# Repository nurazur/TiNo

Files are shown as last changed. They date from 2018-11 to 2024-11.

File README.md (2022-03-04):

# TiNo
[German Version](https://github.com/nurazur/TiNo/blob/master/LIESMICH.md)

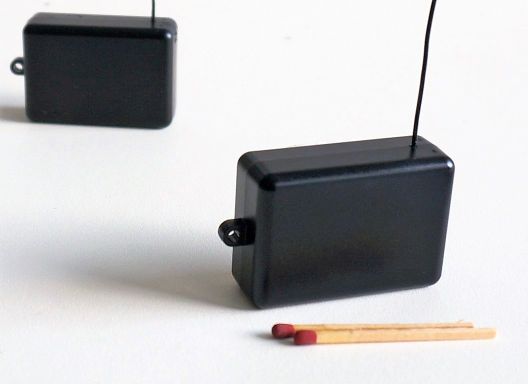
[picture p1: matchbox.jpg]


"**TI**ny **NO**de": battery powered wireless sensor or wireless actor.
Target of the project is the development of small size , cost effective battery powered wireless sensors. The sensors communicate with gateways, like a raspberry pi.
The targets are:

- low cost (BOM under 5 Euro, as of 2020)
- very small size (matchbox)
- ultra low sleep current
- long battery life time: 5 years and more on a CR2032 cell
- long range (what ever this means :-), but its realy long)
- simple to build up
- communication security
- Plug&Play Firmware

Sensors can be almost any, like temperature, relative humidity, air pressure, altitude meter, light intensity, UV Index,
movement detectors, Reed switches, etc. However sensors have to be specified to work down to 2.2V. Otherwise the charge of the battery can not be fully used.

PCBs fit into low cost PVC boxes with the size of a matchbox that are readily available on the market.  

# Features
## General
- Voltage from ca. 1.8V to 3.6V
- Operates with a CR2032 cell up to 5 years
- various PCBs fitting into selected PVC boxes

## Sensors
- HTU21D
- SHT21, SHT20, SHT25
- SHT30, SHT31, SHT35
- BME280 (air pressure sensor)
- DS18B20 (ubiquitous temperature sensor)
- MAX31865 (PT100 temperature Sensor)
- AM312 (PIR movement sensor)
- I2C Bus based sensors can easily be integrated
- 4 digital GPIOs
- up to 4 analog GPIO's (dependent on hardware)

## Radio
- RFM69CW, RFM69HCW, RFM95 Module
- bidirectional communication
- ISM Band (Europe: 433MHz / 868MHz, US:315MHz / 915Mhz)
- 2GFSK Modulation
- Center frequency adjustable
- Frequency correction can be calibrated
- Transmit power from -18 dBm to 20dBm, 10 dBm typ.
- Link budget up to 120dB
- sensitivity -105 dBm typ.
- range t.b.d., but its looong!
- RF communication encrypted
- FEC (Forward Error Correction)
- Interleaver

## Baseband
- Atmel (Microchip) ATMega328p-au
- 32kByte Flash
- sleep current < 2µA mit external crystal 32.768kHz
- sleep current ca. 4µA with internal RC oscillator
- 1 MHz clock allows operating voltage down to 1.8V
- 8 MHz clock for gateway receiver
- I2C bus
- min 4 additional GPIO
- CPU can be locked to avoid reading the flash code

## System / Software
- Open Source Software C++
- Software can easily be adopted individually
- Programming tool is Arduino IDE
- Configuration of Nodes via serial interface (FTDI Adapter)
- configuration data and calibration data reside in EEPROM
- EEPROM encrypted
- Flashing
  - using ISP Adapter or
  - serial with FTDI Adapter and Bootloader
- up to 4 external interrupts (i.e. push buttons) can be configured

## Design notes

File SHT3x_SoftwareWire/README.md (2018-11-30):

# SHT3x
## Arduino library for Sensirion temperature and humidity sensors SHT30, SHT31 & SHT35.
The light version, modiofied by nurazur 2018 for use in mobile Sensors (Code reduction to the bare minimum) and for SoftwareWire
Check for /examples for examples of different use cases.  

The datasheet I followed is:  
https://www.sensirion.com/fileadmin/user_upload/customers/sensirion/Dokumente/2_Humidity_Sensors/Sensirion_Humidity_Sensors_SHT3x_Datasheet_digital.pdf  
For more simple version check the SimpleSHT3x library.  

The constructor structure:  
SHT3x(    int Address = 0x44, //I2C device address, 0x44 or 0x45  
        ValueIfError Value = Zero, //What to return in case of errors. Zero or PrevValue  
        uint8_t HardResetPin = 255, //Number of pin RESET connected to (input from 100 to 255 if not used)  
        SHT3xSensor SensorType = SHT30, //Sensor type, SHT30, SHT31 or SHT35.  
        SHT3xMode Mode=Single_HighRep_ClockStretch //Operation mode , look for "enum SHT3xMode"  
); 

Do not forget about the UpdateData() method: this method polls sensors.

### Supports:  
    Temperature data at Celsius, Kelvin and Fahrenheit scales.  
    Relative humidity data.  
    Absolute humidity data at Torr, mm Hg, Pa, bar, technical and standard atmosphere, psi scales.  
    Data integrity (by CRC8 algorithm) (datasheet/section 4.12).  
    Temperature, relative and absolute humidity tolerances (in dependence from measured values)  
    Calibration (linear) of temperature and humidity data by factors or by reverse sensor values (2 points)  
    Heater On/Off (integrated to SHT3x sensor) (datasheet/section 4.10)  
    Different sensor actions modes (datasheet/section 4.3)  
    Reset: soft (I2C) and hard (by corresponding pin) (datasheet/section 4.9)  
    
### Do not supports:  
    Action in periodic mode (datasheet/section 4.5)  
    Interrupts (datasheet/section 3.5)  

Note 1: by default, the data from sensor updates not faster, than 2 times a second.
For faster update use SetUpdateInterval(uint32_t UpdateIntervalMillisec); but do not exceed the datasheet values (10 measurments per second (100 ms)) because of sensor self-heating (datasheet/section 4.5, at the end of Table 9)  

Note 2: The sensor type affects the tolerance values only.   

Created by Risele for everyone's use (profit and non-profit).  

ALL THESE WOR_DS  
ARE YOURS EXCEPT  
RISELE  
ATTEMPT NO  
namechangING THERE  
USE THEM TOGETHER  
USE THEM IN PEACE

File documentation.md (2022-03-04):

# Projekt Tino
"**TI**ny **No**de" : battery operated wireless sensor or wireless actor.
Object of the project is the development of small size, cost effective battery powered wireless sensors. The sensors communicate with gateways, like a Raspberry Pi. Targets of the development are:

- low cost (BOM below 5 Euro)
- very small size (matchbox)
- very low power consumption
- ultra low sleep current
- long battery life time: 5 years and more on a CR2032 cell
- long range (what ever this means :-), but its really long)
- simplicity
- high grade of communication security
- Plug&Play Firmware
- a certain grade of manufacturability.

Sensors can be almost any, like temperature, relative humidity, air pressure, altitude meter, light intensity, UV Index,
movement detectors, Reed switches, etc. However sensors have to be specified to work down to 2.2V. Otherwise the charge of the battery can not be fully used.

PCBs fit into low cost PVC boxes with the size of a matchbox that are readily available on the market.

## Content
- [Project Description](#project-description)
- [Concept](#concept)
- [How does it work?](#how-does-it-work)
- [IDE setup](#ide-setup)
- [Compile and Flash Software](#compile-and-flash-software)
- [Configuration of Nodes](#configuration-of-nodes)
- [Build a TiNo](#build-a-tino)
- [Electronics](#electronics)
- [Printed Circuit Boards (PCB's)](#printed-circuit-boards-pcbs)
- [Mechanics](#mechanics)

## Project Description
A TiNo sensor takes measurements periodically, for example a temperature reading, and transmits the result over the air to a base station (gateway). The gateway then processes the received data and stores them, which, for example, can be used by cloud services. TiNo can also be used as a monitoring system, for example it can report the opening of doors or windows.

The development started searching for commercially available and affordable enclosures and estimating the required real estate for the PCB's.
The result is a wireless sensor which has been optimized in all important areas in the size of a matchbox. I call it TINO = **TI**ny **NO**de. Later it will become the **TI**ny **N**etw**O**rk. Regarding software there is still a lot of work to do.

## Concept
### Minimal Cost:
<p align='justify'>At the moment the choice of the  ATMega328 processors together with the RFM69CW RF-module is the lowest possible cost variant for makers. There is no need for a LDO or a DC-DC converter. All modules, including the sensor, are directly operated by a 3V CR2032 cell, two AAA batteries or two AA batteries. More cost savings can be realized if the PCB real estate is minimized. This way more PCB's can be accommodated on a multi-frame PCB in production. </p>

### Minimal Size
Due to the used frequencies in the ISM Band we cannot downsize the sensor as desired, without big concessions to performance.
With dimensions of approximately 35 x 50 mm I have had good experiences in the 868MHz ISM Band. The 433MHz ISM Band works sufficient as well.
### Minimal current consumption
Consistent implementation of the possibilities of the ATMega328 processor. Optimization of RF parameters. Optimization of powering the system. Use of energy-saving sensors.
### Maximum Battery life time
The life time of a battery depends on its use case. Mainly Four elements contribute to the battery life time:

1. The battery. TiNo sensors use a CR2032 coin cell. This kind of battery has a typical usable capacity of 200mAh.
2. energy consumption of a single transmit pulse. I optimized the duration of the transmit pulse as well as the power consumption during the pulse.
3. Sleep current. The sleep current was optimized as well. using an external 32.678kHz clock crystal the processor works in sleep mode like a RTC (Real Time Clock). This way I measured sleep currents as low as 1.2µA. Without clock crystal the internal RC oscillator is used. This will consume approximately 4µA, which still is a very good value.
4. The number of transmit pulses per time. With a rate of one pulse per minute the current consumption of the pulses dominates. With a rate of one pulse per hour the sleep current outweighs the current consumption of the transmit pulses.

A typical temperature/humidity sensor transmits one pulse every 30 minutes, so a CR2032 cell should have a life time of 5 years or even longer.
In case you understand German, [in my Blog](https://nurazur.wordpress.com/2018/02/25/batterielebensdauer-eines-tx-nodes-verlaengern-mit-einem-32-768-khz-quarz/) I have explained all this extensively.
### Maximum Range
Optimization of the Layouts. Optimization of the RF parameters. this increases RF sensitivity considerably. Optimization of the RF driver to achieve maximum transmit power.
### Maximum Security
The transmitted message is encrypted. The key cannot be read from flash memory if the processor has been locked for reading before. "Rolling codes" are used so that each message is more or less unique and makes eavesdropping pretty difficult.
### Simplicity
In some areas there is still room for improvement, admitted.
#### Plug&Play Firmware
There is a module available in the Boards Manager of the Arduino IDE.
#### Straightforward Hardware
## How does it work?
<p align='justify'>A TiNo is a sensor which takes periodically measurements and transmits the results using radio frequencies to a gateway. Usually this gateway consists of another TiNo, configured as a receiver node, and a Raspberry Pi. The two communicate over the serial interface. The receiving TiNo receives the RF signal, decodes it, filters out erroneous data and communicates plausible data to the Raspberry Pi. The message is acknowledged if requested. The protocol used between the receiving TiNo and the Raspberry Pi is simple, but it could possibly follow any arbitrary standard, for example RFLink.</p>
<p align='justify'>By default TiNos can react to external events, for example Reed contacts.
A program running on the Raspberry Pi processes and records the data coming from the receiving TiNo. A web application can use these data and display them graphically. However, this is not (yet) part of the TiNo project.
Two TiNo's are required to establish a wireless connection. One needs to be configured as a "sender", the other one as a "receiver".</p>

### Hardware architecture
TiNo Boards are developed as simple as possible:
- directly powered by a 3V battery.
- ATMega328p-au processor
- RFM69CW or RFM69HCW or RFM95 module from HopeRF
- Footprint for a HTU21D/SHT20/SHT21/SHT25 on PCB
- any I2C Sensor can be connected.
- Battery holder (CR2032 cell)
- ISP (in-System-Programming) Adapter, 2x3 Pin row
- FTDI Adapter, 1x6 Pin row
- configurable GPIO's usable for external digital events
- Status LED
- some Boards have a optional SMA socket for an external antenna
- all PCB's are conceptually developed for defined enclosures, but can be used otherwise (of course!)
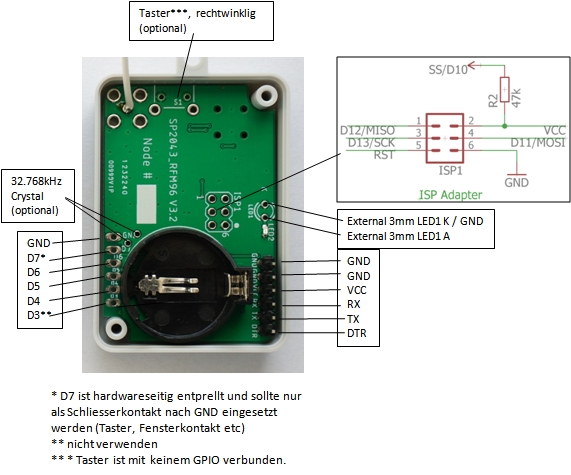
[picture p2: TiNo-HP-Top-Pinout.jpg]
TiNo HP Anschlüsse Oberseite

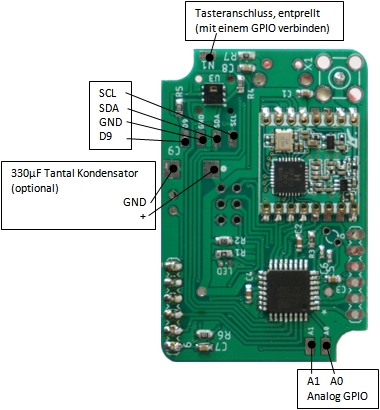
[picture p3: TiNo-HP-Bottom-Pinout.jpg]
TiNo HP Anschlüsse Unterseite

### Software architecture
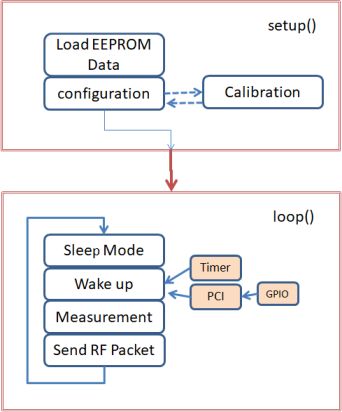
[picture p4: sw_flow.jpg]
TiNo Sensor Software architecture


## IDE setup
### prerequisites
- You should have some solder equipment and solder skills to build up the hardware.
- You should know what the Arduino IDE is.
- You need to install the Arduino IDE on your PC.
- You should know what a "sketch" is.
- The following is easier to understand if you know what a "bootloader" is.
- some basic knowledge of C/C++ is an advantage, but not necessarily required.

In case all that don't tell you anything, then it is better to purchase ready flashed and configured product. Write me an e-mail to nurazur@gmail.com and I will send you the current price list.

### Install TiNo library
- launch Arduino IDE.
- open `File->Preferences`.
- at `Additional Boards Manager URL's` enter this link:
`https://raw.githubusercontent.com/nurazur/TiNo/master/package_tino_index.json`
- Navigate to `Tools->Board`: this opens a long list. at the top, click `Boards Manager...`
- search for `Tiny Node AVR Boards` in the boards manager.
- choose the latest release.
- click `Install`.
This installs all libraries required to operate the wireless protocol.

### Install additional required libraries  
The required sensor libraries are included in the TiNo release package. They can be found in the github repository as well.<br>
Following libraries are required additionally:
- *DallasTemperature*
- *OneWire*

<p align ='justify'>These libraries are currently not part of the TiNo software package. They need to be manually installed by copying into the standard Arduino library directory. The idea behind is that the libraries are of general purpose and could be used for any other arduino project.</p>

## Compile and Flash Software
[Burn Fuses, Flash Bootloader](#burn-fuses-flash-bootloader)<br>
[Define System Password](#define-a-network-system-password)<br>
[Define Sensor Type](#define-the-sensor-type)<br>
[Flash Software](#flash-software)<br>

There are two possibilities to flash code. provided you build a TiNo from scratch, you will need a programmer with [ISP Adapter](https://www.arduino.cc/en/Tutorial/ArduinoISP) in both cases. In case you purchase TiNo's they will be delivered with bootloader already installed.
A programmer can easily be set up using a Arduino UNO. The two possibilities are:
1. Flash a bootloader using the ISP Programmer as a one-time action. Sketches are then flashed using the bootloader and the serial interface, which is in common with the serial interface of the sketch. Advantage: during the development phase you use the same serial connection to flash and test.
2. Flash the sketch directly  without bootloader over the ISP using the programmer. Since there is no bootloader code in flash memory, there is more flash space available.

### Burn Fuses, Flash Bootloader
<p align='justify'>The receiver (or "gateway") needs to be compiled for a board with 8MHz clock. Likewise, a sensor (sender) has to be compiled for a board with 1 MHz clock.
For that, choose the version depending on your personal preferences `Tools->Setup->Gateway, 8MHz, internal Osc` (without bootloader) or `Tools->Setup->Gateway, 8MHz, int.Osc., bootloader` (with bootloader). Analog to the setup of receiver boards, for a sensor board you need to chose, depending on your personal preferences, `Tools->Setup->Sensor, 1MHz, internal Osc.` (no bootloader) or `Tools->Setup->Sensor, 1MHz, int. Osc., bootloader` (with bootloader).</p>

<p align='justify'>Now the "Fuses" have to be programmed ("burned"). These are 3 Bytes of specially protected memory in the processor which determine the general behavior of the processor; The meaning of each bit of these 3 bytes can be studied in the processor's data sheet.
On [this web page](http://www.engbedded.com/fusecalc) it is possible to define or to decode the meaning. Generally speaking we define clock frequency of the processor,  external crystal or internal clock, and the size of the bootloader - if any.</p>
<p align='justify'>The process happens in the Arduino IDE simultaneously with flashing the bootloader. In the life time of a TiNo you do this exactly one time. After that you can flash sketches without "burning fuses". The term "Burn Bootloader" is somewhat confusing, because even if you don't want to use a bootloader you need to select this option just to burn the fuses. It should read exactly as "burn fuses and then flash bootloader". The bootloader itself is a pre-compiled program and is part of the TiNo libraries.</p>

To burn fuses and flash the bootloader (one-time operation):
1. Chose the correct TiNo board `Tools->Board: TiNo Boards` and then `Tools->Setup->...`
2. Connect Arduino Programmer to the ISP connector on TiNo board
3. in the IDE, select the COM Port of the programmer `Tools->Port`
4. In case a Arduino (z.B.UNO) is used as programmer: Click `Tools->Programmer` and then chose "Arduino as ISP" (***not*** "ArduinoISP"!)
5. Click `Tools->Burn Bootloader`. If you choose to burn fuses only, there will be an error message, because the Arduino IDE looks for a bootloader file to be flashed, but there isn't one defined. Don't worry, everything is alright -this is a bug on my side.

#### Alternative: avrdude
<p align='justify'>Power users tend to setup the tool `avrdude` and use it directly from the command line (terminal window). This has a variety of advantages: one can easily query the fuse settings, flash or erase the EEPROM, or flash pre-compiled sketches (.hex files) directly. This also allows to use batch files, so that several steps during the configuration phase can be worked on one by one with one single command. </p>

### Define a Network System Password
The system password is a defined byte sequence in the source code of TiNo _*.ino_ files.
it looks like this (the passphrase is between quotes): `#define KEY  "TheQuickBrownFox"`
The passphrase can consist of letters, numbers or special characters, the only important thing is that it has to have a length of exactly 16 characters. The passphrase `TheQuickBrownFox` is the default.
****It is strongly recommended to change this for your own network.****

### Define the Sensor Type

### Flash Software
#### Flash Software on a board *with* Bootloader:
1. Chose the correct TiNo board `Tools->Board: TiNo Boards` and then `Tools->Setup->...
2. Connect the TiNo board using a FTDA Adapter to your PC. Chose COM Port of serial interface: `Tools->Port`
3. Click `Sketch->Upload`. The sketch will be compiled and then the binary executable is uploaded to the board.

#### Flash  Software on a board *without* Bootloader:
1. Chose the correct TiNo board `Tools->Board: TiNo Boards` and then `Tools->Setup->...`
2. When using a Arduino (i.e. UNO) as programmer: Chose `Tools->Programmer` -> "Arduino as ISP" (***not*** "ArduinoISP"!). Otherwise chose the programmer that you use
3. Connect the programmer with your PC and select its COM Port `Tools->Port`
4. Click `sketch->Upload using Programmer`. Now the sketch will be compiled. Possibly there are warnings, but they can be ignored. Then the binary executable code is uploaded into the flash of the board.

## Configuration of Nodes
After flashing the code TiNo sensor and receiver sketches do not fully work (unfortunately), they need configuration. The EEPROM has to be filled with useful data, the device needs "calibration".

### EEPROMer Python tool
After powering up the TiNo, it reads the EEPROM data. Since the data are encrypted, TiNo decrypts the data and calculates the checksum.

#### If the calculated checksum is identical to the checksum in the EEPROM:
on the serial port TiNo sends the word "CAL?". If 'y' is received within 250ms, then TiNo will enter calibration mode.
Otherwise, if for example no answer is received, then TiNo sends the word "timeout". This is just a debug message. It shows that everything is OK. You see this message only when using a terminal program, such as minicom or TeraTerm.

#### If the calculated checksum is *not* identical to the checksum in the EEPROM:
TiNo enters calibration mode.

The EEPROMer tool or TiNo calibration tool is called *tinocal_v0xx.py*. It runs with python 3 (tested with version 3.7) as well as with Python 2.7. It work under Linux as well as Windows OS.<br>
There are several command line options. The 2 most important are the serial port spec and the Baud rate. The Baud rate for a sender is 4800 Bd, for a receiver it is 38400 Bd. Both the sensor and the receiver can be calibrated with the same tool.

*Important notice:*

> The Tool **tinocal** of version 1 works only on Python 2.7, it throws errors on Python 3.
> The tinocal tools are different for version 1, version 2 and version 3 of TiNo software, they are <em>not</em> compatible with each other. Software of version 1 needs to be calibrated with tinocal version 1, software of version 2 needs to be calibrated with tinocal.009.py of version 2, and software of version 3 needs to be calibrated with tinocal_v010.py of version 3.

<p align ='justify'>When starting the tinocal tool, first the serial port is opened. In case a real FTDA adapter (with DTR line) is connected, this will reset the TiNo. If the DTR line isn't available on your serial adapter, the DTR pin on the TiNo board has to be put to GND manually for a short period. Tinocal then does nothing but listening for the string <em>'CAL?'</em> on the serial interface. As soon as it has received the trigger word, it sends an acknowledgement <em>'y'</em>. The TiNo board on the other side of the interface waits for the acknowledgement and enters calibration mode if it receives <em>'y'</em> within 250ms.</p>

<p align ='justify'>As soon as tinocal signals the calibration mode, the password must be entered. This password is the system password, identical to the <em>KEY</em> parameter in the source code of the sketches. This key also is used to encrypt the messages sent over the air. The EEPROM is encrypted because otherwise a thief could reconfigure a TiNo completely (and do unintentional actions with it) without knowing the encryption key used to transmit messages.</p>

#### Enter Password:
- either: enter the password that is pre-configured in tinocal: `pwd<Enter>` This is just an abbreviation so you don't have to type the password again and again.
- or: there is a command line option that uses the pre-configured password: `-pwd`
- or:  type the password. (it has to be identical with the compiled password in the sketch):<br> `pw,<password><Enter>`

Now tinocal should display "Pass OK", and the actual configuration process can start.
The following commands are supported:

`help` lists all options.

| Command  | Description  | Syntax |
|---|:---|:---|
|`exit` | terminate program
|`help`  or `?` | print this help text
|`c` | measure ADC and store in EEPROM.
|`copy` or `cp` | copy file content to EEPROM. | `cp,<filename>`
|`ri`| read 16 bit integer from EEPROM. | `ri(ead),<addr>`
|`cs`| verify checksum.
|`ft` | write temperature/frequency-correction data table to EEPROM.
|`g` or `get` | store EEPROM content to file. | `g(et),<filename>`
|`ls` or `a`| List EEPROM configuration data.
|`m` | Measure VCC with calibrated values
|`quit` or `q`| terminate program
|`read`  or `r` | read from EEPROM. | `r(ead),<addr>`
|`rf`| read float from EEPROM. | `ri(ead),<addr>`
|`s` | request checksum update and store in EEPROM.
|`t` | send a test RF packet |(ver. 3.x or later)
|`to`| start sending radio OOK signal |(ver. 3.x or later)
|`ts`| put radio into sleep mode |(ver. 3.x or later)
|`tt`| read temperature from RFM69 device |(ver. 3.x or later)
|`vddcal` | calibrate VCC measurement. | `v(ddcal),<VCC at device in mV>`
|`write` or `w`|  write value to to EEPROM.  | `w(rite),<addr>,<value>`
|`wf` | write float value to EEPROM. | `wf,<addr>,<value>`
|`wl` | write long int value to to EEPROM.  | `wl,<addr>,<value>`, value format can be hex
|`wu` | write unsigned int value to EEPROM. | `wu,<addr>,<value>`
|`x` | exit calibration mode and continue with loop()

<p align='justify'>Generally the tinocal tool is interactive, so one can "manually" write meaningful data into the EEPROM. However in practice this is sufficient only for making little changes or for testing the integrity of the EEPPROM data.
More automation is in the works.</p>
The most important activities can be triggered by command line options. Following options are supported:

| Option | Description  | 
|:---|:---|
|-pwd | Send the password as stored in tinocal
|-cs| read checksum from EEPROM
|-ls | List EEPROM data
|-cp,< filename>| copy content of a file to TiNo
|-s | calculate and save checksum to TiNo
|-x | encrypt EEPROM and save Data
|-q | quit tinocal

Here a example of a command line:

`python tinocal_v009.py COM8 38400 -pwd -cp,receive_eeprom.cfg -ls -s -x -q`

In this example tinocal connects to a TiNo board with COM8, 38400 Bd and processes the list of command line options from left to right:
1. `-pwd` sends the password that is provided in the source code of tinocal (can be changed by the user)
2. `-cp,receive_eeprom.cfg` copy the content of the file `receive_eeprom.cfg` from PC to TiNo board.
2. `-ls` list content of the EEPROM.
3. `-s` calculate and save check checksum.
4. `-x` leave calibration mode
5. `-q` quit tinocal

### EEPROM explained:
Following parameters are defined in EEPROM:

| Parameter |  Value | Description |
|:----|:----|:----|
|NODEID| 0-255 | identification of TiNo
|NETWORKID | 0-255 | identification of the network, typically 210 *)
|GATEWAYID | 0-255 | Target identification (Gateway) to which messages are sent
|VCCatCAL | typ. 3300 mV | Value of the supply voltage at the time of calibration
|VCCADC_CAL | typ. 350 | calibrated ADC value.
|SENDDELAY | 0 - 65535 | time in seconds/8 that passes between measurements (max. 145 hours, approx. 6 days). If 0, the RTC timer is deactivated. **)
|FREQBAND | 43, 86 | 43 for the 433MHz Band, 86 for the 868MHz Band
|FREQ_CENTER | i.e. 865.000 | exact center frequency of the sender (must be identical for the entire network)
|TXPOWER | 0-31 | 31 = maximum power, 0 = minimum power, in 1dB Steps (valid for RFM69CW/HCW)
|REQUESTACK | 0 or 1 | defines if a received message must be acknowledged (1) or not (0)
|LEDCOUNT | 0 - 255 | set number of times a received messages is announced by a short blink of the LED ***)
|LEDPIN | 0, 8 | TiNo Pin of the LED (normally Pin D8). A value of zero indicates that the LED isn't used and the pin is free for a interrupt
|RXPIN | 0 | not used. TiNo uses the module *Serial*.
|TXPIN | 1 | not used.
|SDAPIN | 0 - 21 | default: 18 (A4) - SDA pin of the I2C bus
|SCLPIN | 0 - 21 | default: 19 (A5) - SCL pin of the I2C bus
|I2CPOWERPIN | 0- 21 | default: 9 (D9) power supply for sensor components
|PCI0PIN | 0 -21, 128 | usually 3 - 9. Pin used for interrupt PCI0
|PCI0TRIGGER | 0b0000xxxx | kind of interrupt. see below.
|PCI1PIN | 0 -21, 128 | unused interrupts are declared with the value 128
|PCI1TRIGGER |  0b0000xxxx|
|PCI2PIN | 0 -21, 128 |
|PCI2TRIGGER|  0b0000xxxx|
|PCI3PIN| 0 -21, 128 |
|PCI3TRIGGER|  0b0000xxxx|
|USE_CRYSTAL_RTC | 0 or 1 | Version <=2: do not edit!<br>Version 3 and later: editable
|ENCRYPTION_ENABLE | 0 or 1 | 1 = encrypt messages
|FEC_ENABLE | 0 or 1 | 1 = use Forward Error Correction
|INTERLEAVER_ENABLE | 0 or 1 | 1 = use interleaver
|EEPROM_VERSION_NUMBER | auto | **do not edit!** written by the sketch.
|SOFTWAREVERSION_NUMBER| auto | **do not edit!** written by the sketch.
|TXGAUSS_SHAPING | 0,1,2,3 | default: 0. determines BT of Gauss Shaping (advanced)
|SERIAL_ENABLE | 0 or 1 | default 1. determines the activation of the serial port
|IS_RFM69HW | 0 or 1 | 0 = RFM69CW is used. 1 =  RFM69**H**CW is used
|PABOOST | 0, 1, 2, 3| default: 0. Only valid for RFM69HCW: determines the High-Power parameters (advanced)
|FDEV_STEPS | +/- | Frequency correction at room temperature (simple calibration of the 32 MHz crystal of the RFM)
|CHECKSUM | auto | calculated at the end of calibration process and automatically updated (Option 's')

Neue Parameter ab Version 3:

| Parameter |  Value | Description |
|:----|:----|:----|
SENSORCONFIG|0 - 63|bit field configuring sensors supported by hardware
RADIO_T_OFFSET|-128 ... 127| offset in degrees*10 to calibrate the RFM69 temperature sensor
USE_RADIO_T_COMP| 1 or 0 | enable/disable temperature dependent frequency correction
LDRPIN|14,15,16,17| analog GPIO Pin that is connected to a LDR.
PIRPOWERPIN|0-21|GPIO connected to the + (Vdd) terminal of the PIR.  Data terminal needs to be connected to PCI1PIN.
PIRDEADTIME|0-255|period during which the PIR does not respond after it has triggered.
ONEWIREDATAPIN|0-21| Pin where the DS18B20 Data terminal is connected.
PCIxGATEWAYID| 0-255 |target Node when a PCIx interrupt is triggered. x= 0 ... 3

#### Notes:
*) 210 is just to be compatible with the older RFM12B module. On RFM12B modules this value is fixed and cannot be changed.

**) Setting SENDELAY=0 deactivates the timer and activates sleep mode. The microprocessor wakes up only on external interrupts ("PCI").

<p align = 'justify'>***) In standard use cases the LED isn't necessary, it is actually a debug utility. It is possible to determine if the LED blinks when a message is sent. A number > 0 defines the number of messages after start up that are accommodated with a short blink. The default is 1.</p>

#### PCI Trigger Byte Bit Setting:

PCIxTrigger bits 0 and 1:

| Bit Setting | Definition |
|---|---|
|0b0000xx00 | LOW
|0b0000xx01 | CHANGE
|0b0000xx10 | FALLING (default)
|0b0000xx11 | RISING

PCIxTrigger bits 2 and 3:

| Bit Setting | Definition |
|---|---|
|0b000000xx | INPUT
|0b000001xx | OUTPUT
|0b000010xx | INPUT_PULLUP  (default)

Example:
0b00001010 = 0x0A - 10 (Dec) = INPUT_PULLUP und FALLING
This is the default. The internal pullup is part of the hardware debounce circuit with a resistor and a capacitor.

## Building a TiNo
Due to the limited bill of material (BOM) and its simple construction it is really straightforward to build a TiNo, provided some elementary solder skills
### Pre-requisites: What is needed?
#### Hardware
- USB-Serial Adapter: FTDI or compatible, CH340 works as well. Pay attention to the pin-out, und always adjust the jumper or switch to 3.3V! The adapter should have the DTR line available.
- ISP-Programmer (if TiNo is built up from scratch)
- Gateway: something that can open a serial port, read and write to it, display and store messages like a PC, Raspberry Pi, ESP8266,...
- solder iron and accessories. it should be n fine soldering iron for electronics, not an iron that is operated with gas.

#### Software
- Python
- Arduino IDE

### Printed Circuit Board (PCB)
PCB's can be ordered at [seeedstudio](https://www.seeedstudio.com/fusion_pcb.html). From order to delivery it takes 3 weeks, however the quality is good at a reasonable price. Layouts are designed with [Autodesk Eagle](https://www.autodesk.com/products/eagle/overview) and are available at my [github repository](https://github.com/nurazur/TiNo/tree/master/eagle).
### Mechanics (Enclosures)
Two PCB designs are presented:
- The first PCB uses a RFM69HCW / RFM95 pin-out and fits to [Strapubox SP2043 enclosure](http://strapubox.de/modules/uploadmanager11/admin/index.php?action=file_download&file_id=163&location_id=0). In principle this is suited to build a LoRa Node, software is available online.
- The second PCB uses the pin-out of the RFM69CW / RFM12B and fits into [Strapubox MG307 enclosure](https://de.elv.com/search?sSearch=strapubox+MG307). This is the lowest cost variant, the enclosure costs less than 1 EUR, and the RFM69CW can be procured at lower cost than a RFM69HCW.

## Electronics
### Circuit Diagram
The special thing about TiNo is its simplicity. The circuit diagram is really straightforward.

- The core functionality is delivered by its microprocessor and the RF module. The RF module communicates over its SPI bus, these are GPIO's D10(SS) D11(MOSI), D12(MISO) und D13(SCK). Additionally the RF driver needs an external interrupt, GPIO 2 (D2 is used for this). This interrupt triggers when a packet has been received or a packet has been sent.
- These exact GPIO's are being used by the ISP (In-System-Programmer) adapter, because flashing the processor uses the SPI bus as well.
- There is a 10kOhm pullup at the  SS pin (D10) to avoid the RF module to interfere on the SPI bus during the programming process. This pullup causes no additional current in sleep mode.
- Optionally the PCB can be populated with an clock crystal (32.768 kHz). The crystal needs two load capacitors of 6pF or 12pF depending on its specification.
- At start-up and for testing the device a LED is very useful. The LED is connected to digital GPIO 8 (D8). Depending on the TiNo PCB the LED can be used in SMD or wired form factor.
- For practical reasons a FTDI adapter is available. its pin-out is identical to the pin-out of the Arduino Pro Mini. For this reason there are adapters available with this exact pin-out.
- The I2C Bus is connected to GPIO Ports A4 (SCL) und A5(SCK). I2C bus components are supplied through GPIO D9, so in sleep mode they are completely powered off and don't cause sleep currents.  Both lines of the I2C need pull-up resistors. If a HTU21D/SHT2x module is used instead of the on-board IC, then those resistors aren't needed because the pull-ups are already mounted on the module.

### Bill of Material
The prices for components fluctuate strongly. Therefore, the prices shown below are only to be understood as a guide.

| Component | Price | Remark |
|---|---|----|
|ATMega328p-au | ~ 1.20 EUR | 40 pin TQFP
|RFM69CW | ~ 1.50 EUR  |
|HTU21D Sensor | ~ 1.30 EUR | IC's in DFN-6 package cost the same in low qty.
|enclosure | ca. 0.70  - 1.20 | depending on type
|Battery holder | 0.10 |
|other |0.05 | resistors, capacitors, LED in SMD form factor*)

*) a low amount of different values is required, which simplifies the BOM.

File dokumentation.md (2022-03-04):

# Projekt Tino
"**TI**ny **NO**de" : Batteriebetriebener Funksensor oder Funk-Aktor.
Ziel dieses Projekts ist die Entwicklung schnurloser Funk Sensoren,
die über Batterien versorgt werden und z.B. mit dem Raspberry Pi kommunizieren.
Die Entwicklung hat zum Ziel:

- minimale Kosten
- minimale Grösse
- minimaler Stromverbrauch
- maximale Batterielebensdauer
- maximale Reichweite
- maximale Sicherheit
- maximale Einfachheit
- Plug&Play Firmware

Als Sensor kann man so ziemlich alles verwenden, ob Temperatur, Luftfeuchtigkeit, Luftdruck, Höhenmesser, Lichtintensität, UV Index,
Anwesenheitssensoren, Magnetschalter, Erschütterungs-Sensoren, Feuchtigkeitsmesser usw also im Prinzip alle Arten von Sensoren.

Die Leiterplatten passen in im Handel erhältlichen PVC Gehäusen, welche in etwa die Grösse einer Streichholzschachtel haben.
## Inhalt
- [Beschreibung des Projekts](#beschreibung-des-projekts)
- [Das Konzept](#das-konzept)
- [Wie Funktionierts?](#wie-funktionierts)
- [IDE Einrichten](#ide-einrichten)
- [Software Kompilieren und Flashen](#Kompilieren-und-Flashen)
- [Nodes Konfigurieren](#nodes-konfigurieren)
- [Nachbau](#nachbau)
- [Elektronik](#elektronik)
- [Leiterplatten](#leiterplatten)
- [Mechanik](#mechanik) (Gehäuse)

## Beschreibung des Projekts
Der TiNo Sensor macht periodisch eine Messung, z.B. der Umgebungstemperatur und sendet das Ergebnis mit einer kurzen HF Aktivität ("Puls") an eine Basisstation. Diese bereitet das Signal auf und speichert das Ergebnis in einer Datenbank, die z.B. von einem Cloud Service ausgewertet werden kann. Der TiNo kann gleichzeitig auch Ueberwachungsaufgaben übernehmen, wie z.B das Oeffnen einer Türe melden.

Die Idee zu dieser Entwicklung wurde bei mir durch ein Projekt im [deutschen Raspberry Pi Forum](https://forum-raspberrypi.de/forum/thread/7472-batteriebetriebene-funk-sensoren/) ausgelöst.
Ich möchte mich an dieser Stelle nocheinmal herzlich bei allen Beteiligten für die harte Arbeit die dahinter steckt bedanken.
Da wurde mit viel Energie und Enthusiasmus ein System zum Senden und Empfangen von Sensordaten "zusammengebaut", was zur Entwicklung der "TinyTx4" und "TinyRX3" Platinen auf der Basis des ATtiny84a Prozessors geführt hat.

Zunächst ging es mir um technische Verbesserungen: Optimierung des Link-Budgets, ein binäres, wesentlich kürzeres Protokoll, Verbesserungen beim Stromverbrauch und beim Ruhestrom, ich experimentierte HF-seitig unter anderem mit FEC (Forward Error Correction), Interleavern, Baud Raten und Filterbandbreiten, und schliesslich war klar: ein anderer Prozessor muss her, der ATtiny mit seinen 8kB Flash kann nicht mithalten.

Ich begann von vorne. Bei der Gelegenheit habe ich die TiNo Platinen an das Gehäuse und ihren Zweck angepasst und nicht umgekehrt.
Herausgekommen ist ein in allen Parametern optimierter Funksensor in der Grösse einer Streichholzschachtel, welchen ich TINO = **TI**ny **NO**de nenne. Später kann man daraus dann das **TI**ny **N**etw**O**rk machen, denn auf der Softwareseite, speziell am Gateway gibt es noch unendlich viel Arbeit.

## Das Konzept
### Minimale Kosten:
Momentan ist die Auswahl des ATMega328 Processors mit dem RFM69CW HF-Modul die kostengünstigste Variante. Weiterhin kann auf LDO's oder DC-DC Konverter verzichtet werden, da alle Module direkt von einer 3V CR2032 Zelle, zwei AAA Batterien oder zwei AA Batterien betrieben werden können. Weitere Kosten können durch verkleinern der Leiterplatte erzielt werden, so kann man sog. Nutzen (Panels) erzeugen bei denen das selbe Layout 4/6/8 mal auf eine Leiterplatte gebracht wird.
### minimale Grösse
Aufgrund der verwendeten Frequenzen kann man die Baugrösse eines Sensors nicht beliebig verkleinern ohne grosse Zugeständnisse an die Performance zu machen.
Mit Platinenabmessungen von ca. 35 x 50 mm habe ich im 868MHz ISM Band gute Erfahrungen gemacht. Im 433MHz ISM Band funktioniert das ebenfalls durchaus zufriedenstellend.
### minimaler Stromverbrauch
Konsequente Umsetzung der Möglichkeiten des ATMega328 Prozessors. Optimierung der HF Parameter. Optimierung der Stromversorgung. Verwendung stromsparender Sensoren.
### maximale Batterielebensdauer
Die Lebensdauer der Batterie hängt vom Einsatzfall ab. Sie setzt sich im Wesentlichen aus den vier folgenden Komponenten zusammen:
1. die Batterie. Der TiNo hat einen CR2032 Knopfzellenhalter eingebaut. Eine CR2032 hat geschätzt 200mAh nutzbare Kapazität.
2. die Energie die bei einem Sendeimpuls verbraucht wird. In diesem Projekt habe ich die Dauer des Impulses sowie seine Leistung optimiert.
3. der Ruhestrom. Auch der Ruhestrom wurde optimiert. Mit externem Uhrenquarz 32.678MHz arbeitet der Prozessor im Sleep Modus wie eine RTC (Real Time Clock), ich habe Ruheströme von 1.2µA gemessen. Ohne den Uhrenquarz verwendet man den internen RC Oszillator, da messe ich ca. 4µA, das ist aber immer noch ein sehr guter Wert.
4. die Anzahl der Sendepulse pro Zeit. bei einer Rate von einem Puls pro Minute überwiegt der Stromverbrauch der Sendepulse. Bei einer Rate von einem Puls pro Stunde überwiegt der Stromverbrauch durch den Ruhestrom.
Bei einem typischen Temperatur/Luftfeuchte Sensor, der alle 30 Minuten eine Messung sendet kann eine CR2032 Zelle 5 Jahre oder länger halten.
[In meinem Blog](https://nurazur.wordpress.com/2018/02/25/batterielebensdauer-eines-tx-nodes-verlaengern-mit-einem-32-768-khz-quarz/) gibts das Ganze sehr ausführlich erklärt.
### maximale Reichweite
Optimierung des Layouts. Optimierung der HF Parameter. Dadurch verringert sich die Eingangsempfindlichkeit drastisch. Optimierung des HF Treibers um maximale Sendeleistung zu erreichen.
### maximale Sicherheit
Das Sendeprotokoll ist verschlüsselt. Der Schlüssel kann nicht aus dem Flash gelesen werden wenn das Basisband versperrt wurde. Um zu verhindern dass ein einmal aufgezeichnetes Signal bei Wiederholung etwas auslöst wird ein "rolling code" verwendet, der sicherstellt dass jedes Protokoll "einmalig" ist.
### Einfachheit
Da gibts noch Raum für Verbesserung.
#### Plug&Play Firmware
Es wird ein Modul im Boards Manager der Arduino IDE bereitgestellt.
#### Unkomplizierte Hardware
## Wie Funktionierts?
Ein TiNo ist ein Sensor der periodisch eine Messung vornimmt und diese per Funksignal an ein Gateway überträgt.  Dieses Gateway besteht normalerweise aus einem als Empfänger konfigurierten TiNo der an einen Raspberry Pi über dessen seriellen Port angeschlossen ist. Das Gateway empfängt die Funksignale, dekodiert sie und wenn die Daten sinnvoll sind werden diese an den Raspberry Pi weitergegeben. Ausserdem quittiert das Gateway die Nachricht auf Aufforderung. Das zwischen Gateway und Raspberry von mir verwendete Protokoll ist einfach, könnte aber im Prinzip jedem beliebigen Standard folgen, z.B. RFLink.
TiNos können standardmässig auch auf externe Signale reagieren, z.B Tueröffner Kontakte.
Auf dem Raspberry Pi läuft ein Python Programm, welches die vom Gateway ankommenden Pakete aufbereitet und in eine Datenbank schreibt. Eine Web Applikation kann dann auf diese Daten zugreifen und daraus Graphiken etc machen. Dies ist aber (noch) nicht Gegenstand des TiNo Projekts.
Um eine Funkverbindung herzustellen braucht man zwei TiNos, einen als Sensor konfigurierten und einen als Gateway konfigurierten.

### Hardwarearchitektur
Die TiNo Boards sind so einfach wie möglich aufgebaut:
- direkt von einer 3V  Batterie gespeist
- ATMega328p-au Prozessor
- RFM69CW oder RFM69HCW oder RFM95 Modul von HopeRF
- Footprint für einen HTU21D/SHT20/SHT21/SHT25 ist auf der Leiterplatte
- Anschlussmöglichkeiten für einen I2C Sensor beliebiger Wahl.
- Ein Batteriehalter
- ISP (in-System-Programming) Adapter, 2x3 Pin Leiste
- FTDI Adapter, 1x6 Pin Leiste
- je nach Board verschiedene GPIO's die man für alle möglichen digitalen Ereignisse (z.B. Tastendruck) konfigurieren kann
- Status LED
- auf manchen Boards ist eine optionale SMA Buchse vorgesehen (externe Antenne)
- alle Boards sind jeweils für ein bestimmtes Gehäuse konzipiert, können aber auch anderweitig eingesetzt werden.
TiNo HP Anschlüsse Oberseite
TiNo HP Anschlüsse Unterseite
### Softwarearchitektur
TiNo Sensor Software Architektur

## IDE Einrichten
- Arduino IDE starten.
- `File->Preferences` öffnen.
- Unter `Additional Boards Manager URL's` diesen Link eintragen:
`https://raw.githubusercontent.com/nurazur/TiNo/master/package_tino_index.json`
- Navigiere zu `Tools->Board`: eine lange Spalte öffnet sich. Ganz oben auf `Boards Manager...` klicken
- Im Boards Manager nach `Tiny Node AVR Boards` suchen.
- die neueste Freigabe auswählen.
- Auf `Install` klicken.
Dies installiert die Bibliotheken die zum Betrieb des Funkprotokolls gebraucht werden.
### Empfänger (Gateway)
Der Empfänger oder besser "Gateway" wird für ein Board mit 8 MHz Taktfrequenz kompiliert.
hierzu je nach Wahl die Version `Tools->Setup->Gateway, 8MHz, internal Osc` (ohne Bootloader) oder `Setup->Gateway, 8MHz, int.Osc., bootloader` (mit Bootloader)
 auswählen. Dann müssen die "Fuses" dementsprechend programmiert werden.
Dies sind drei Byte geschützter Speicher im Prozessor, die das Verhalten des Prozessors bestimmen; was die einzelnen Bits im Einzelnen bedeuten steht im Datenblatt des Prozessors.
Auf [dieser Webseite](http://www.engbedded.com/fusecalc) kann man die Fuses bestimmen, bzw. dekodieren was sie bedeuten. Im Wesentlichen stellen wir hier ein mit welchem Takt der Prozessor arbeiten soll, ob mit externem Quarz oder internem Taktgeber und ob ein Bootloader verwendet werden soll oder nicht.

In der Arduino IDE wird dieser Vorgang zusammen mit dem Flashen des Bootloaders vorgenommen. Dies macht man für jedes Board genau einmal, danach kann man Sketches flashen ohne die Fuses brennen zu müssen. Der Ausdruck "Burn Bootloader" ist etwas verwirrend, denn wenn wir die Variante ohne Bootloader wählen, müssen wir diesen Vorgang dennoch durchführen um die Fuses zu "brennen".

Fuses flashen (einmaliger Vorgang):
1. Programmer an den ISP des Boards anschliessen
2. COM Port des Programmers auswählen `Tools->Port`
3. Klick auf `Tools->Burn Bootloader`

Alternativ kann man, wenn man ein Poweruser ist, das Tool *avrdude* einrichten und direkt von der Kommandozeile aus verwenden. Dies hat eine Reihe von Vorteilen, da man damit einfach die Fuses abfragen kann, das EEPROM löschen/flashen oder auch fertig kompilierte .hex Dateien direkt auf das Board flashen kann ohne mühsam durch die Arduino IDE klicken zu müssen.
### Sender
Der Sender oder besser "Node" (Knoten in einem Netzwerk) wird für ein Board mit 1 MHz Takt kompiliert. Die "Fuses" müssen dementsprechend programmiert werden. Der Vorgang ist mit dem beim Empfänger identisch.

### Weitere Bibliotheken Installieren
Die notwendigen Bibliotheken für die Sensoren sind im TiNo Package enthalten. Sie stehen auch im Github Repository.
Folgende Bibliotheken braucht man zusätzlich zur Installation des TiNo Boards:
- *DallasTemperature*   (für den DS18B20 Sketch)
- *OneWire*             (für den DS18B20 Sketch)

Diese Bibliotheken sind ab Version 3.0.3 mit im TiNo Package enthalten.

## Kompilieren und Flashen
Dazu braucht man, zumindest kurzfristig, einen Programmer mit [ISP Adapter](https://www.arduino.cc/en/Tutorial/ArduinoISP).
Zum Flashen der Boards gibt es zwei Konzepte. In beiden Fällen braucht man einen Programmer mit [ISP Adapter](https://www.arduino.cc/en/Tutorial/ArduinoISP).
Diesen kann man sich leicht mit einem Arduino UNO oder einem Arduino Nano selbst herstellen. Die Alternativen sind:
1. Einmalig mit dem ISP Programmer auf das Board einen Bootloader flashen. Der eigentliche Sketch wird dann über das serielle Interface des Boards geladen. Vorteil: Während der Entwicklungsphase kann man mit dem selben Interface flashen und testen, ohne das Interface wechseln zu müssen.
2. Den Sketch direkt ohne Bootloader mit einem ISP Adapter flashen. Vorteil: In der Produktionsphase können Nodes in einem einzigen Arbeitsschritt geflasht werden. Da kein Bootloader vorhanden ist, hat man auch mehr Flash Speicher zur Verfügung.

### mit FTDI und USB-Seriell Adapter
Einmaliger Vorgang, wenn man das Board zum ersten mal startet:
- Wenn man einen Arduino (z.B.UNO) als Programmer benutzt: Bei `Tools->Programmer` "Arduino as ISP" auswählen (nicht "ArduinoISP"!)
- Ansonsten den Programmer seiner Wahl auswählen
- COM Port des Programmers einstellen unter `Tools->Port`
- Setup auswählen: "bootloader", je nach Anwendung ist das 'Sensor' oder 'Gateway'.
- `Tools->Burn Bootloader` klicken. Jetzt wird das Board mit den zuvor gewählten Parametern konfiguriert und der Bootloader geflasht.

Normales Flashen:
- COM Port des seriellen Interfaces auswählen: Tools -> Port:
- in der IDE Sketch -> Upload klicken. Jetzt wirdder Sketch kompiliert und geflasht.

### Flashen mit ISP Adapter und Programmer
Einmaliger Vorgang, wenn man das Board zum ersten mal startet:
- Setup je nach Anwendung auswählen, "Sensor" oder "Gateway". Die Option ohne Bootloader wählen.
- den Programmer seiner Wahl auswählen
- COM Port des Programmers einstellen unter `Tools->Port`
- `Tools->Burn Bootloader` klicken.

Normales Flashen:
- Wenn man einen Arduino (z.B.UNO) als Programmer benutzt: Bei `Tools->Programmer` "Arduino as ISP" auswählen (nicht "ArduinoISP"!)
- Ansonsten den Programmer seiner Wahl auswählen
- COM Port einstellen unter `Tools->Port`
- In der Arduino IDE `sketch->Upload using Programmer` klicken. Jetzt kompiliert der Sketch, eventuell mit Warnungen (die man aber ignorieren kann) und lädt den binären Code auf das Board hoch.

## Nodes Konfigurieren
Nach dem Flashen sind die Nodes und die Gateways noch nicht betriebsbereit (leider, wird verbessert). Das EEPROM muss zuerst mit sinnvollen Daten gefüllt, "kalibriert" werden.
### EEPROMer Python tool
nach dem Start eines TiNos liest das TiNo Board das EEPROM. Da die Daten verschlüsselt sind, werden sie zunächst entschlüsselt und die Prüfsumme gebildet.
Wenn die Prüfsumme mit der aus dem EEPROM gelesenen übereinstimmt:
- über den seriellen Port wird der String "CAL?" gesendet. Wenn innerhalb von 250ms ein 'y' zurückkommt, geht der TiNo in den Kalibriermodus.
Kommt keine Antwort, sendet der TiNo, nur als Debugnachricht, ein "timeout". Also nicht wundern über das Timeout, das zeigt an dass alles in Ordnung ist. Man sieht es allerdings nur wenn man das TiNo Board direkt mit einem Terminalprogram (z.B. minicom oder TeraTerm) verbindet.

Wenn die Prüfsumme nicht übereinstimmt:
- Der TiNo geht direkt inden Kalibriermodus.

Da serielle Ports von Computer zu Computer verschieden sind gibt es eine Kommandozeilenoption für den Port. Die Baudrate für den Sender TiNo ist 4800 Baud. Für ein Gateway braucht man moeglichst hohe Baudraten; im Moment ist sie auf 38400 Baud festgelegt. Für beide Konfigurationen kann das selbe Eepromer Tool verwendet werden.

**Wichtige Hinweise:**
Das EEPROMer Tool ist geht mit Python 2.7 oder Python 3.x und wurde auf Linux (Debian) und Windows10 getetstet.
Das EEPROMer Tool tinocal der Version 1 ist in Python 2.7 geschrieben aber läuft unter Python 3 nicht.
Die Python Tools der Versionen 1, Version 2 und Version 3 sind untereinander nicht kompatibel! Firmware der Version 1 muss man mit dem Tool der Version 1 abgleichen, Firmware der Version 2 und später mit dem tool tinocal_v009.py, Firmware der Version 3 mit tinocal_v010.py

Wenn man das EEPROMer Tool startet, öffnet es zunächst den seriellen Port. An einem FTDI Adapter (mit herausgefuehrter DTR Leitung) bewirkt das, dass der angeschlossene TiNo neu startet. Wer keinen Adapter mit DTR Leitung zur Verfügung hat, muss zum Neustart des TiNo die DTR Leitung kurz auf Masse legen und wieder freigeben. Dann wartet das Tool auf das 'CAL?' vom TiNo, und sendet ggf. das 'y' sofort zurück um den Kalibriermodus zu erzwingen.
Sobald das Tool meldet dass man im Kalibriermodus ist, muss man das Passwort eingeben. Dies ist mit dem *KEY* Parameter im Source Code identisch. Derselbe KEY wird auch zum Verschlüsseln des HF Pakets benutzt. Das EEPROM ist verschlüsselt, weil sonst ein Dieb einen TiNo ohne weiteres komplett umkonfigurieren könnte und damit wild in der Gegend herumfunken kann (oder noch Schlimmeres anrichten kann), ohne dass er das Passwort kennen müsste.

Passwort eingeben:
- entweder das im Eepromer Tool hinterlegte Passwort verwenden: `pwd<Enter>` eingeben
- oder ein anderes Passwort verwenden (muss aber immer mit dem kompilierten Passwort identisch sein): `pw,<Passwort><Enter>` eingeben

Nachdem das Tool "Pass OK" meldet, kann man mit dem Konfigurieren beginnen.
Folgende Syntax wird von dem Tool verstanden:
`help` listet die Optionen auf:

| Kommando | Beschreibung  |
|:---|:---|
|`exit` | terminate program
|`help`  or `?` | print this help text
|`c` | measure ADC and store in EEPROM.
|`copy` or `cp` | copy file content to EEPROM. syntax: cp, <filename>
|`cs`| verify checksum.
|`ft` | write temperature / frequency-correction table to EEPROM
|`g` or `get` | store eeprom content to file. Syntax: `g(et),<filename>`
|`ls`| Liste die  EEPROM Konfigurationsdaten.
|`m` | Measure VCC with calibrated values
|`pw`| Passwort. Syntax: `pw,<passwort>`
|`pwd`| Passwort des Auslieferungszustands (default)
|`quit` | beende das Programm
|`read`  or `r` | read from EEPROM. Syntax: `r(ead),<addr>`
|`ri`| read 16 bit integer from EEPROM. Syntax: `ri(ead),<addr>`
|`rf`| read float from EEPROM. Syntax: `ri(ead),<addr>`
|`s` | request checksum update and store in EEPROM.
|`t` | send a test RF packet
|`to`| start sending radio OOK signal
|`ts`| put radio into sleep mode
|`tt`| read temperature from RFM69 device
|`vddcal` | calibrate VCC measurement. Syntax: `v(ddcal),<VCC at device in mV>`
|`write` or `w` |  write value to to EEPROM.  Syntax: `w(rite),<addr>,<value>`
|`wf` | write float value to EEPROM. Syntax: `wf,<addr>,<value>`
|`wl` | write long int value to to EEPROM.  Syntax: `wl,<addr>,<value>`, value format can be hex
|`wu` | write unsigned int value to EEPROM. Syntax: `wu,<addr>,<value>`
|`x` | exit calibration mode and continue with loop()

Das Tool ist ursprünglich interaktiv, d.h. man greift "manuell" auf das EEPROM zu und kann es so konfigurieren. Allerdings ist das nur bis zu einem bestimmten Grad praktisch, z.B. wenn man nur mal schnell eine ID ändern will, oder wenn man nur die Integrität des EEPROMs feststellen will.
Wenn man mehr machen will/muss, wäre eine automatisierte Version praktisch. Ich arbeite daran.

Im Moment kann man die wichtigsten Aktionen durch die Kommandozeile auslösen.
Unterstützt werden zur Zeit folgende Optionen:

| Option | Beschreibung  |
|:---|:---|
-pwd | Sende das im Tool hinterlegte Passwort
-cs|   lies die Prüfsumme vom EEPROM
-ls | Liste der EEPROM Werte
-cp,<Dateiname>| Kopieren des Inhalts einer Konfigurationsdatei zum TiNo
-s | berechnen und speichern der Prüfsumme
-x | EEPROM verschlüsseln und Daten abspeichern
-q | Tool beenden

eine Kommandozeile sieht dann beispielsweise so aus:

`python tinocal_v010.py COM8 38400 -pwd -cp,receive_eeprom.cfg -ls -cs -x -q`

In diesem Fall verbindet sich das Eepromer Tool mit dem TiNo Board auf COM8, 38400 Baud und arbeitet dann die Liste der Optionen in der Reihenfolge ab, also:
1. `-pwd` sendet das im Programm hinterlegte Passwort an da TiNo Board
2. `-cp,receive_eeprom.cfg` kopiert den Inhalt der Datei `receive_eeprom.cfg` vom PC auf das TiNo Board
2. `-ls` listet den Inhalt des EEPROMs.
3. `-cs` liest die Prüfsumme und prüft sie.
4. `-x` verlässt den Kalibriermodus
5. `-q` beendet das Tool

### EEPROM Speicher erklärt:
Diese Parameter sind derzeit im EEPROM gespeichert:

| Parameter |  Wert | Beschreibung |
|:----|:----|:----|
NODEID| 0-255 | die Identitfizierung des TiNo
NETWORKID | 0-255 | Identifizierung des Netzwerks, typisch 210 *)
GATEWAYID | 0-255 | Das Ziel (Gateway) zu dem Nachrichten gesendet werden
VCCatCAL | typ. 3300 mV | Wert der Versorgungsspannung in mV zum Zeitpunkt der Kalibrierung
VCCADC_CAL | typ. 350 | der ADC Wert der bei Anliegen von VCCatCAL kalibriert wurde
SENDDELAY | 0 - 65535 | Zeit in Sekunden/8 die zwischen zwei Messungen vergehen soll (Maximal 145 Stunden, ca 6 Tage). Bei einem Wert von 0 wird der RTC timer deaktiviert. **)
FREQBAND | 43, 86 | 43 für das 433MHz Band, 86 für das 868MHz Band
FREQ_CENTER | z.B. 865.000 | die genaue Mittenfrequenz des Senders (muss für das gesamte Netzwerk identisch sein)
TXPOWER | 0-31 | 31 = maximale Sendeleistung, 0 = minimale Sendeleistung in 1dB Schritten
REQUESTACK | 0 oder 1 | legt fest ob ein empfangenes Telegramm quittiert werden soll (1) oder nicht (0)
LEDCOUNT | 0 - 255 | legt fest ob ein gesendetes Telegramm von einem kurzen Blinken der LED begleitet wird und wie oft ***)
LEDPIN | 0, 8 | Pin an dem die LED hängt (beim TiNo Pin D8). Bei einem Wert von Null wird die LED gar nicht verwendet und ist frei für einen Interrupt verwendbar
RXPIN | 0 | ohne Bedeutung, es wird das Modul *Serial* verwendet.
TXPIN | 1 | ohne Bedeutung.
SDAPIN | 0 - 21 | normalerweise 18 (A4)  Pin der für den SDA des I2C Busses verwendet wird
SCLPIN= | 0 - 21 | normalerweise 19 (A5) Pin der für den SCL des I2C Busses verwendet wird
I2CPOWERPIN | 0- 21 | normalerweise 9 (D9). Pin der für die VCC der I2C Komponenten verwendet wird
PCI0PIN | 0 -21, 128 | normalerweise 3 - 9, Pin der für den Interrupt PCI0 benutzt wird
PCI0TRIGGER | 0b0000xxxx | Triggerart des Interrupts. Wird unten erklärt
PCI1PIN | 0 -21, 128 | ein nicht benutzter externer Interrupt wird mit dem Wert 128 angezeigt
PCI1TRIGGER |  0b0000xxxx|
PCI2PIN | 0 -21, 128 |
PCI2TRIGGER|  0b0000xxxx|
PCI3PIN| 0 -21, 128 |
PCI3TRIGGER|  0b0000xxxx|
USE_CRYSTAL_RTC | 0 oder 1  | Version 2: nicht editieren! wird vom Sketch eingetragen. Ab Version 3:  editierbar
ENCRYPTION_ENABLE | 0 oder 1 | legt fest ob das Telegramm verschlüsselt werden soll
FEC_ENABLE | 0 oder 1 | legt fest ob Forward Error Correction eingesetzt werden soll
INTERLEAVER_ENABLE | 0 oder 1 | legt fest ob ein Interleaver zum Einsatz kommt.
EEPROM_VERSION_NUMBER | auto | **nicht editieren!** wird vom Sketch eingetragen
SOFTWAREVERSION_NUMBER| auto | **nicht editieren!** wird vom Sketch eingetragen
TXGAUSS_SHAPING | 0,1,2,3 | normalerweise 0. Legt fest ob und mit welchem BT Gauss Shaping vorgenommen wird (fortgeschritten)
SERIAL_ENABLE | 0 oder 1 | normal 1. legt fest ob standardmässig der Serielle Port aktiviert sein soll
IS_RFM69HW | 0 oder 1 | 0 : es handelt sich um einen RFM69CW. 1: eshandelt sich um einen RFM69**H**CW
PABOOST | 0, 1, 2, 3| normalerweise 0. nur für RFM69HCW: legt die High-Power Parameter fest (fortgeschritten)
FDEV_STEPS | +/- | Frequenzkorrektur bei Raumtemperatur (einfache Kalibrierung des 32 MHz Quarzes des RFM)
CHECKSUM | auto | wird beim Konfigurieren berechnet und dann eingetragen (Option 's')

Neue Parameter ab Version 3:

| Parameter |  Wert | Beschreibung |
|:----|:----|:----|
SENSORCONFIG|0-63|Bitfeld welches festlegt welche Sensoren von der Hardware unterstützt werden
RADIO_T_OFFSET|-128 ... 127| Offset in Grad*10 um die genauigkeit des RFM Temperatur sensors zu kalibrieren
USE_RADIO_T_COMP| 0 oder 1 | Temperaturabhängige Frequenzkorrektur aktivieren
LDRPIN|14,15,16,17| analoger GPIO Pin wo der LDR angeschlossen ist
PIRPOWERPIN|0-21|GPIO wo der + Anschluss des PIR verbunden ist. Datenpin geht an PCI1PIN
PIRDEADTIME|0-255|Zeit in der der PIR nach dem Auslösen nicht reagiert.
ONEWIREDATAPIN|0-21| Pin wo der DS18B20 Data Pin angeschlossen ist.
PCIxGATEWAYID| 0-255 |Ziel Node wenn ein PCIx Interrupt ausgeloest wurde. x= 0 ... 3

*) 210 ist um mit dem RFM12B Modul kompatibel zu sein. Wert kann bei diesem Modul nicht geändert werden.

**) Wird SENDELAY=0 gesetzt, wird der Timer deaktiviert und  der Sleep Modus des Prozessors aktiviert. Dieser wacht jetzt nur noch bei externen Interrupts ("PCI") auf.

***) Da die LED eigentlich nicht gebraucht wird und nur zum Test einer einwandfreien Funktion dient, kann eingestellt werden ob die LED beim Versenden eines Telegramms aufleuchten soll. Eine Zahl > 0 stellt ein bei wie vielen Telegrammen nach dem Start die LED noch blinken soll. Normalerweise auf 1 gesetzt. Wird LEDCOUNT=255 gesetzt, blinkt die LED immer wenn ein Paket gesendet wird.

PCI Trigger Byte Bitbelegung:

PCIxTrigger bits 0 and 1:

| Bitbelegung | Bedeutung |
|---|---|
0b0000xx00 | LOW
0b0000xx01 | CHANGE
0b0000xx10 | FALLING (Normaleinstellung)
0b0000xx11 | RISING

PCIxTrigger bits 2 and 3:

| Bitbelegung | Bedeutung |
|---|---|
0b000000xx | INPUT
0b000001xx | OUTPUT
0b000010xx | INPUT_PULLUP  (Normaleinstellung)

Beispiel:
0b00001010 = 0x0A - 10 (Dec) = INPUT_PULLUP und FALLING
Dies ist die Normaleinstellung. Der interne Pullup ist Teil der Entprellschaltung mit einem externen Widerstand und einem Kondensator.

---> Bild mit Entprellungsschaltung <----
## Nachbau
Aufgrund der überschaubaren Stückliste und des einfachen Aufbaus ist der Nachbau wirklich kinderleicht, ein wenig Lötfertigkeit vorausgesetzt.
### Vorausetzungen: Was braucht man?
#### Hardware
- USB-Seriell Adapter (FTDI oder kompatibel, CH340 geht auch aber auf das Pinning achten!, und immer den Jumper oder den Schalter auf 3.3V einstellen!)
- ISP-Programmer
- Gateway: etwas das einen seriellen Port öffnen, lesen, schreiben, anzeigen und speichern kann (PC, Raspberry Pi, ESP8266,...)
- Lötkolben und Zubehör. Es sollte ein feiner Lötkolben für Elektronik sein, nicht gerade einer der mit Gas betrieben wird.

#### Software
- Python (am Raspberry Pi bereits vorinstalliert)
- Arduino IDE

### Leiterplatten
Die Leiterplatten bestelle ich gerne bei [seeedstudio](https://www.seeedstudio.com/fusion_pcb.html). Das dauert zwar 3 Wochen von der Bestellung bis zur Lieferung, dafür ist die Qualität aber sehr gut zum vernünftigen Preis. Die Layouts wurden mit [Autodesk Eagle](https://www.autodesk.com/products/eagle/overview) entworfen und sind [hier](https://github.com/nurazur/TiNo/tree/master/eagle) hinterlegt.
### Mechanik (Gehäuse)
ich stelle hier zwei verschiedene Leiterplattendesigns vor:
Die erste Leiterplatte verwendet die RFM69HCW bzw. RFM95 Pinbelegung und ist für das [Strapubox SP2043 Gehäuse](http://strapubox.de/modules/uploadmanager11/admin/index.php?action=file_download&file_id=163&location_id=0) konzipiert. Damit kann man im Prinzip auch einen LoRa Node verwirklichen, entsprechende Software gibt es passend im Netz.
Die zweite Leiterplatte ist mit der Pinbelegung des RFM69CW (kompatibel mit RFM12B) und für das [Strapubox MG307 Gehäuse](https://www.elv.de/strapubox-kunststoff-gehaeuse-mg-307-abs-45-x-30-x-22-mm-grau.html). Dies ist die kostensparendste Variante, da das Gehäuse weniger als 1 EUR kostet und auch der RFM69CW deutlich günstiger zu haben ist als ein RFM69HCW.
## Elektronik
### Schaltplan erklärt
Das Besondere am TiNo ist dass die Schaltung wirklich nicht kompliziert ist.

Das Herzstück ist der Prozessor mit dem HF Modul. Das HF Modul kommuniziert über den SPI Bus, das sind die GPIO's D10(SS) D11(MOSI), D12(MISO) und D13(SCK). Ausserdem benutzt der Treiber einen Interrupt an GPIO D2, der auslöst wenn Daten empfangen werden. Derselbe GPIO D2 wird auch benutzt um das Ende einer Sendesequenz zu signalisieren.
Die selben GPIO's werden vom ISP Adapter benutzt, denn die Programmierung des Prozessors erfolgt ebenso mit SPI Bus. Damit sich das HF Modul beim Programmieren über ISP nicht angesprochen fühlt, braucht es einen 10kOhm Pullup an der SS Leitung (D10). Im Sleep Mode beeinflusst dieser Widerstand den Ruhestrom nicht.

Optional kann der Prozessor im Sleep Modus mit einem externen Uhrenquarz (32.768 KHz) bestückt werden. Der Quarz benötigt noch zwei Lastkondensatoren von je 6pF oder 12pF, je nach Bauart des Quarzes.

Bei der Inbetriebnahme und zum Testen ist eine LED unglaublich hilfreich. Diese wird an GPIO D8 angeschlossen. je nach TiNo Boardausführung kann die LED in SMD und/oder bedrahteter Bauform eingesetzt werden.

Der Bequemlichkeit halber gibt es einen FTDI Adapter. Das Pinout des Adapters ist mit der Pinbelegung eines Arduino Pro Mini identisch, deshalb gibt es auch jede Menge USB-TTL Konverter im Netz mit genau diesem Pinout.

Der I2C Bus wird auf den GPIO Ports A4 (SCL) und A5(SCK) angeschlossen. I2C Bus Komponenten werden durch GPIO D9 versorgt, damit sie im Sleep Modus keinen Strom verbrauchen. Beide Leitungen des I2C Busses brauchen Pullup Widerstände. Wird anstelle des HTU21D/SHT2x Chips ein Modul verwendet, braucht man diese Widerstände nicht da sie auf dem Modul bereits montiert sind.

### Stückliste
Die Preise für Bauteile schwanken stark. Daher sind die angegebenen Preise nur als Anhaltspunkt zu verstehen

| Bauteil | Preis | Bemerkung |
|---|---|----|
ATMega328p-au | ca. 1.20 EUR | März 2022: ca 7.00 EUR
RFM69CW | ca. 1.50 EUR  |
HTU21D Sensor | ca. 1.30 EUR | IC's im DFN-6 Gehäuse kosten fast das selbe (ausser im 50er Pack)
Gehäuse | ca. 0.70  - 1.20 | je nach Typ
Batteriehalter | 0.05 |
Kleinteile |0.05 | Widerstände, Kondensatoren, LED in SMD Bauform *)

*)Ich habe darauf geachtet dass man nicht allzu viele verschiedene Werte benoetigt.

### Messergebnisse

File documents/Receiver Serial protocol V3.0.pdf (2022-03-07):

## TiNo Receiver serial Protocol 3.0

Port Parameters:
Gateway | 38400 Bd 8N1 | 8 Data bits, no parity bit, 1 Stop bit
Sensor | 4800 Bd 8N1 | 8 Data bits, no parity bit, 1 Stop bit

Receiver Message Protocol:
human readable byte sequence, coded with Ascii characters (0-127):

<nodeID><white space><VariableName1>=<value>&<VariableName2>=<value>&...\n

N | LZ | V1 | = | W1 | & | V2 | = | W2 | & | … | & | Vn | = | Wn

\n

N Node ID of Sender
LZ | Separation sign (white space)
Vx | Variable name x
Wx | Value of Variable x – Values must be Integer numbers
& | separation sign (Ampersand)
\n | new line sign (Ascii sign 10)

Available Variables
VariableName Parameter (ger.) | paramter(engl.) | Unit Min | Max | scale factor
d | Entfernung Entfernung | distance distance | cm | -1 | 300 | 10
h | Luftfeuchte | humidity | %rH | 0 | 120 | 100
he | Höhe | height | m | -450 | 100
p | Luftdruck | Air pressure | hPa | 300 | 100
r | Reed-Kontakt | contact | --- | 0 | 1 | 1
t | Temperatur | temperature | degC -40 | 600 | 100
t1 | Temperatur | temperature | degC -40 | 90 | 100
t2 | Temperatur | temperature | degC -40 | 90 | 100
v | Batteriespannung | battery voltage | V | 0 | 5
int | Interrupt | interrupt | --- | 0 | 0xFFFF | 1
rssi | Signalstärke | RSSI | dBm -130 | 0 | 10
lqi | Kanalgüte | link quality indicator --- | 0 | 127 | 1
fo | Frequenzversatz | Frequency offset | Hz | 1
c | Zähler | count | --- | 0 | 1
be | Bitfehler | bit errors | --- | 0 | 127 | 1
sy | Synchronisation | synchronized | --- | 0 | 1 | 1
br | Helligkeit | brightness | --- | 0 | 1

Example

### 23 v=3002&c=243&t=3400&h=5650&int=0&rssi=-835&fo=2014&be=0\n

Message from Node 23: VCC=3.002V, Rolling code =243, Temperature = 34.00 degC, humidity=56.5%rH, no interrupts, RSSI=-83.5dBm, Frequency Offset =2014 Hz, no bit errors

Variables can be listed in any sequence.
All variables a node has available are transmitted.

1023

65535

9999
1100

1000

-30000 30000

Variables Details

VariableName Resolution | Description
d | 1 cm/10 = 1 mm | distance as measured by a ultrasonic sensor
h | 0.01% | relative humidity in percent, can be higher than 100% in rare cases
he | 1m/100=1cm | height over sea level
p | 1hPa/100 | Air pressure
r | digital bit value, 1 or 0
t | degC/100 | Temperature from first sensor
t1 | degC/100 | Temperature from 2nd sensor
t2 | degC/100 | Temperature from 3rd sensor
int | 16 bits, 2 bits per interrupt
int8 | int7 | int6 | int5 | int4 | int3 | int2 | int1
| | | | int x: | | b1 | b0
b1 | b0
0 0 | | no interrupt
0 1 | | CHANGE
1 0 | | FALLING FALLING
1 1
rssi | dBm/10 | signal strength as measured by the Gateway
lqi | | a number indicating if the channel is free of noise or interference.
| | 0 is best, 127 is worst. Not applicable to some radios
fo | 1Hz | Frequency offset measured by the receiver. TiNo Modulation is FM.
| | Tight Frequency tuning control (AFC) is crucial. 0 ist best, values above
| | 5000 are somewhat critical
c
be | 1bit | Bit errors in Packet. Only useful when forward Error correction is used.
| | The amount of bit errors the algorithm detected and corrected.
sy | 1 bit
br | 1bit | Brightness. Measured by a LDR connected to a analog GPIO (A0-A4)
| | 0 corresponds to darkness, 1023 is very light. The resolution depends
| | on the type of LDR (GL5537 is recommended)

Changes in version 3.0 compatred to version 2.2:
Variable fo frequency offset removed. In Version 3.x the measurement of this parameter is not possible. Variable br (brightness) added.

Packet counter, rolling over at some point. Can be a 8-bit value or a 16 bit, value depending on implementation

the gateway is keeping track with the senders rolling code (count value). If track ist lost this signal is set to 0

RISING
In some cases the gateway does not know the exact nature of the interrupt trigger. In this case a CHANGE is signalled.

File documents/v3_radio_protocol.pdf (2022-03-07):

The TiNo Radio Data Protocol | V3.0.2

Preamble, mandatory for all Packets

AA | AA | AA | 2D | XX | LEN | LEN Bytes of Data | Preamble is required by RFM69
0 | 1 | 2 | 3 | 4 | 5 | 6 | 7… | mode of operation
Byte | | Remarks
0,1,2 | Preamble for frequency Sync
3 | Syncword 1. fixed to 2D for compatibility with RFM12B
4 | Syncword 2. Network ID, defined by user, set to D2 for compatibility with RFM12B
5 | LEN = length of Data block
6…6+LEN Data Block

Data Block (TiNo Sensor Protocol)

D | S | F | V | C | T | H | P | B | LEN = 8 (optional 12)
Param. | #Bits | Remarks
D | 8 | Destination, the Target ID
S | 8 | Sender Node ID
F | 8 | Flags:
x | 0 | 0 | x | x | x | x | x | x= 1 or 0 depending on function
7 | 6 | 5 | 4 | 3 | 2 | 1 | 0

0 Heartbeat (system is healthy)
| 1 PCI 0
2 PCI 1 | Pin Change Events, mapped to Ports in
3 PCI 2 | EEPROM of Sender. 1 = a event happened, 0 = no event happened
| 4 PCI3
5 0 = TiNo Sensor Protocol, 1= Alternate Protocol
6 ACK Must be set to 0.
7 Request ACK from receiver, when set to 1
V | 12 | unsigned int | Voltage measurement. resolution 1 mV, offset 0 mV
possible values range from 0 to 4096 (0 to 4.096V)
C | 8 | unsigned char | counter, incremented for each packet sent, runs over from 255 to 0
T | 12 | unsigned int | Temperature Measurement
Resolution 0.04 degC, offset +40 degC
encode: | T = ( t[degC] + 40 ) *25
decode: | t[degC] = T/25.0 - 40
H | 8 | unsigned char | Humidity Measurement
Resolution 0.5 %RH, offset 0%RH
encode: | H = h[%RH] * 2
decode: | h[%RH] = H/2.0
P | 22 | unsigned int | Air Pressure Measurement
Resolution: 0.01 hPa, offset 0 hPa
encode: | P = p[hPa] * 100
decode: | p[hPa] = P/100.0
B | 10 | unsigned int | analog Value, for example Brightness Measurement

Data Block - Alternate Protocol (General Description)

D | S | F | C | Any other data
0 | 1 | 2 | 3 | 4…LEN | LEN = user defined , must be modulo 4 if encryption is used
LEN=4 indicates empty data block
Param. | #Bits | Remarks
D | 8 | Destination, the Target ID
S | 8 | Sender Node ID
F | 8 | Flags:
x | 0 | 1 | x | x | x | x | x | x=undefined
7 | 6 | 5 | 4 | 3 | 2 | 1 | 0

0
1
2 | user defined Flags.
3
4
5 | Must be set to 1 (indicates an alternate Protocol)
6 | ACK Must be set to 0.
7 | when set to 1, request ACK from receiver
C | 8 | unsigned char | incremented for each packet sent, runs over from 255 to 0

Data Block - ACK Packet

D | S | F | C | RSSI | T | LEN = 8
Param. | #Bits | Remarks
0 D | 8 | Destination, the Target ID
1 S | 8 | Sender Node ID
2 F | 8 | Flags:
0 | 1 | 0 | x | x | x | x | x | x=undefined
7 | 6 | 5 | 4 | 3 | 2 | 1 | 0

Bit 7: must be 0 to avoid acknoledge of an ack packet
Bit 6: must be one to indicate an ACK
Bit 5: must be 0, indicates the response to a TiNo Sensor Packet
3 FEI | 16 | signed int | Frequency Error Indicator [ frequency Steps ]
1 Step = 61.03515625 Hz, see Data Sheet of RFM69
5 C | 8 | unsigned char | must be identical to the count of the packet that is
acknoledged
6 RSSI | 8 | unsigned char | Received Signal Strength Indicator
rssi[dB] = - RSSI / 2.0
Tells the Sender about the channel quality
7 T | 8 | Temperature Measurement of the receiver's RFM69
resolution: 1 degC/LSB
rough temperature indicator, currently not calibrated, can be wrong by several degrees.

note: FEI, RSSI and Temperature Values of the receiver are currently unused

FEI

Alternate Packet Type 3 | (for BME280)
D | S | F | C | 0x03 | V | T | H | LEN =12
Param. | #Bits | Remarks

D 8
S | 8 | see General Description for alternate Packets

F 8

C 8
0x03 | 8 | Packet Type Identifier, must be 3
V | 12 | unsigned int | Voltage measurement. resolution 1 mV, offset 0 mV
| | | possible values range from 0 to 4096 (0 to 4.096V)
T | 12 | unsigned int | Temperature Measurement
| | | Resolution 0.04 degC, offset +40 degC
encode: | T = ( t[degC] + 40 ) *25
decode: | t[degC] = T/25.0 - 40
H | 8 | unsigned char | Humidity Measurement
| | | Resolution 0.5 %RH, offset 0%RH
encode: | H = h[%RH] * 2
decode: | h[%RH] = H/2.0
P | 24 | unsigned int | Pressure measurement
| | | Resolution: 0.01 hPa, offset 0 hPa
encode: | P=p[hPa] * 100
| | | decode: p[hPa] = P/100.0
Alternate Packet Type 4 | (for up to 3 Temperature sensors)
D | S | F | CLSB | 0x03 | V | T | T1 | T2 | CMSB | LEN =12
Param. | #Bits | Remarks

D 8
S | 8 | see General Description for alternate Packets

F 8

CLSB | 8
0x04 | 8 | Packet Type Identifier, must be 4
V | 12 | unsigned int | Voltage measurement. resolution 1 mV, offset 0 mV
possible values range from 0 to 4096 (0 to 4.096V)
T | 14 | unsigned int | Temperature Measurement | Tmax =615 degC | Tmin= -40 degC
Resolution 0.04 degC, offset +40 degC
encode: | T = ( t[degC] + 40 ) *25
decode: | t[degC] = T/25.0 - 40
T1 | 12 | unsigned int | Temperature Measurement | Tmax = 123.8 degC | Tmin = -40 degC
T2 | 12 | unsigned int | Temperature Measurement | Tmax = 123.8 degC | Tmin = -40 degC
CMSB | 6 | unsigned int | Counter MSB

P

Alternate Packet Type 5 | humidity sensor and additional temperature reading (DS18B20 or MAX31865)
D | S | F | CLSB | 0x05 | V | T | H | T2 | B | LEN =12
Param. | #Bits | Remarks

D 8
S | 8 | see General Description for alternate Packets

F 8

C 8
0x05 | 8 | Packet Type Identifier, must be 5
V | 12 | unsigned int | Voltage measurement. resolution 1 mV, offset 0 mV
possible values range from 0 to 4096 (0 to 4.096V)
T | 12 | unsigned int | Temperature Measurement | Tmax =615 degC | Tmin= -40 degC
Resolution 0.04 degC, offset +40 degC
encode: | T = ( t[degC] + 40 ) *25
decode: | t[degC] = T/25.0 - 40
H | 8 | unsigned char | Humidity Measurement Resolution 0.5 %RH, offset 0%RH
encode: | H = h[%RH] * 2
decode: | h[%RH] = H/2.0
T1 | 14 | unsigned int | Temperature Measurement | Tmax = 615.32 degC Tmin = -40 degC
B | 10 | unsigned int | Analog Reading i.e. Brightness | values: 0 - 1023

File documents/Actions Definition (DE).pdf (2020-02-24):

## TiNo Actions Definition

EEPROM Mapping:

Address | | Parameter
479 | 480 | CRC16 Checksum
from | to
318 | 318 | NUM_ACTIONS | 0<= NUM_ACTIONS <=40
319 | 478 | Action Blocks | 40 X 4 Bytes = 160 Bytes
Action Structure: | 4 Bytes
Node | Der Node auf den gehört wird | N7 | N6 | N5 | N4 | N3 | N2 | N1 | N0 | 0…255
Mask | Bit im Flag Byte das die Aktion auslöst | x | x | x | T | T | T | T | T
Port | Der zu schaltende Pin | R | R | R | P4 | P3 | P2 | P1 | P0 | 0…31
OnOff | Art der Aktion am Pin | D | Pd4 | Pd3 | Pd2 | Pd1 | Pd0 | A1 | A0

N Node des Senders
R reserviert, auf 0 setzen.
P Pin am Empfänger, 5 bit Nummer nach Arduino Pin Enumerierung. A0=14, A1=15, … x reserviert / unbenutzt, auf 0 setzen.
T Trigger bit. Flag Byte wird mit dem Flag Byte des Senders verglichen
D Pin Staus Initialisierung. 0= LOW, 1= HIGH
Pd | Puls Dauer. | Zeit = 2Pd-1 Sekunden. Pd=0 ist 0.5s (Minimum)
nur gültig wenn A = 0b11

A1 A0
0 | 0 | Schalte den Pin LOW
0 | 1 | Schalte den Pin HIGH
1 | 0 | Schalte den Pin um (wenn HIGH: LOW, wenn LOW: HIGH)
1 | 1 | Puls

### TiNo Funksteckdose Beispiel

Fernbedienung Hardware:
D6 Taster, zieht D6 bei Betätigung auf GND | Soll die Funksteckdose einschalten
D7 Taster, zieht D7 bei Betätigung auf GND | Soll die Funksteckdose ausschalten

Fernbedienung Konfiguration:
NODEID | 1
GATEWAYID | 22
PCI0PIN | 6 | Verbinde Interrupt PCI0 mit Pin D6
PCI0TRIGGER | 2 | Fallende Flanke, mit internem Pull-Up
PCI1PIN | 7 | Verbinde Interrupt PCI1 mit Pin D7
PCI1TRIGGER | 2 | Fallende Flanke, mit internem Pull-Up
REQUESTACK | 1 | Fordere Bestätigung vom Empfänger an
Wenn Taste 1 an D6: PCI 0 wird ausgelöst. Flag Byte: | 1 | 0 | 0 | 0 | 0 | 0 | 1 | 0
Request Ack
TiNo Data Protocol
PCI 0
Wenn Taste 2 an D7: PCI 1 wird ausgelöst. Flag Byte: | 1 | 0 | 0 | 0 | 0 | 1 | 0 | 0
Request Ack
TiNo Data Protocol
PCI 1

Funksteckdose Hardware:
D6 Relais (active HIGH)
D7 Taster zum Ein/Ausschalten (active LOW) D8 Status LED (leuchtet wenn Pin HIGH ist)

Funksteckdose Konfiguration:
NODEID | 22
PCI0PIN | 7 | Verbinde Interrupt PCI0 mit Pin D7
PCI0TRIGGER | 2 | ausgelöst bei fallender Flanke, mit internem Pull-Up

Aktion die das Relais an Port D6 einschaltet und durch die FB ausgelöst wird:
ACTION0.NODE | 1 | Reagiere auf Fernbedienung mit Nodeid 1
ACTION0.PORT | 6 | schalte Pin D6
ACTION0.MASK | 2 | Agiere wenn Bit (PCI0) gesetzt ist. | x | x | x | x | x | x | PCI0 | x
ACTION0.ONOFF | 1 | schalte Pin HIGH | x | x | x | x | x | x | 0 | 1

Aktion die das Relais an Port D6 ausschaltet und durch die FB ausgelöst wird:
ACTION1.NODE | 1 | Reagiere auf Fernbedienung mit Nodeid 1
ACTION1.PORT | 6 | schalte Pin D6
ACTION1.MASK | 4 | Agiere wenn Bit (PCI1) gesetzt ist. | x | x | x | x | x | PCI 1 | x | x
ACTION1.ONOFF | 0 | schalte Pin LOW | x | x | x | x | x | x | 0 | 0

Aktion die das Relais an Port D6 an bzw. ausschaltet und durch den Taster an der Funksteckdose ausgelöst wird:
ACTION2.NODE | 22 | Reagiere auf lokalen Interrupt
ACTION2.PORT | 6 | schalte Pin D6
ACTION2.MASK | 1 | PCI 0 (ausgelöst durch lokalen Taster D7)
ACTION2.ONOFF | 2 | schalte Pin um | x | x | x | x | x | x | 1 | 0

Aktion die die LED an Pin 8 umschaltet und durch den Taster an der Funksteckdose ausgelöst wird:
ACTION3.NODE | 22 | Reagiere auf lokalen Interrupt
ACTION3.PORT | 8 | schalte Pin D8
ACTION3.MASK | 1 | PCI 0 (ausgelöst durch lokalen Taster D7)
ACTION3.ONOFF | 2 | schalte Pin um | x | x | x | x | x | x | 1 | 0

wenn das Dauerleuchten der LED stört, kann man die LED auch nach z.B 1 Sekunde wieder abschalten (Puls mit 1s):
ACTION3.ONOFF | 7 | Puls mit 1 Sekunde Dauer

Aktion die die LED an Port 8 anschaltet und durch die Fernbedienung ausgelöst wird:
ACTION4.NODE | 1 | Reagiere auf Fernbedienung mit Nodeid 1
ACTION4.PORT | 8 | schalte Pin D8
ACTION4.MASK | 2 | Agiere wenn bit PCI0 gesetzt ist. | x | x | x | x | x | x | PCI0 | x
ACTION4.ONOFF | 1 | schalte Pin HIGH | x | x | x | x | x | x | 0 | 1

Auch hier kann man das Dauerleuchten der LED unterbinden:
ACTION4.ONOFF | 7 | Puls mit 1s Dauer (3 fuer einen Puls mit 1/2 Sekunde)

Aktion die die LED an Port 8 ausschaltet und durch die Fernbedienung ausgelöst wird:
ACTION5.NODE | 1 | Reagiere auf Fernbedienung mit Nodeid 1
ACTION5.PORT | 8 | schalte Pin D8
ACTION5.MASK | 4 | Agiere wenn bit PCI1 gesetzt ist. | x | x | x | x | x | PCI 1 | x | x
ACTION5.ONOFF | 0 | schalte Pin OFF | x | x | x | x | x | x | 0 | 0

Anstatt die LED auszuschalten, kann man einen Puls einstellen:
ACTION5.ONOFF | 7 | Puls mit 1s Dauer (3 fuer einen Puls mit 1/2 Sekunde)

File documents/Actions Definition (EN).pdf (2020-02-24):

## TiNo Actions Definition

EEPROM Mapping:

Address | | Parameter
479 | 480 | CRC16 Checksum
from | to
318 | 318 | NUM_ACTIONS | 0<= NUM_ACTIONS <=40
319 | 478 | Action Blocks | 40 X 4 Bytes = 160 Bytes
Action Structure: | 4 Bytes
Node | The Node to Listen to | N7 | N6 | N5 | N4 | N3 | N2 | N1 | N0 | 0…255
Mask | Bit in the Flag Byte that triggers | x | x | x | T | T | T | T | T
Port | The Pin to activate | R | R | R | P4 | P3 | P2 | P1 | P0 | 0…31
OnOff | Action to take on the Port | D | Pd4 | Pd3 | Pd2 | Pd1 | Pd0 | A1 | A0

N Node
R Reserved.
P Pin of Receiver, 5 bit Number representing Arduino Pin Numbering. A0=14, A1=15, … x don't care
T Trigger bit. Flag byte is compared with Flag Byte from Sender
D Pin state at power up. 0= LOW, 1= HIGH
Pd | Pulse duration. | time = 2Pd-1 seconds. Pd=0 is 0.5 seconds (minimum)
only valid when A = 0b11

A1 A0
0 | 0 | turn pin LOW
0 | 1 | turn pin HIGH
1 | 0 | toggle port
1 | 1 | Pulse

TiNo Wireless Smart-Socket Example

Remote Control Hardware:
D6 Tactile switch #1, connects D6 to GND when active Turns Smart-Socket to ON state D7 Tactile switch #2, connects D7 to GND when active Turns Smart-Socket to OFF state

Remote Control Configuration:
NODEID | 1
GATEWAYID | 22
PCI0PIN | 6 | Connect Interrupt PCI0 to Pin D6
PCI0TRIGGER | 10 | Falling Edge, using internal Pull-up
PCI1PIN | 7 | Connect Interrupt PCI1 to Pin D7
PCI1TRIGGER | 10 | Falling Edge, using internal Pull-up
REQUESTACK | 1 | Request Acknoledge of command
If button #1 is active: PCI 0 will be triggered Flag Byte: | 1 | 0 | 0 | 0 | 0 | 0 | 1 | 0
Request Ack
TiNo Data Protocol
PCI 0
If button #2 is active: PCI 1 will be triggered Flag Byte: | 1 | 0 | 0 | 0 | 0 | 1 | 0 | 0
Request Ack
TiNo Data Protocol
PCI 1

Smart-Socket Hardware:
D6 Relais, operating active HIGH
D7 Tactile Switch Button, connects pin to GND when active (active LOW) D8 Status LED (ON at HIGH state of Pin)

Smart Socket Configuration:
NODEID | 22
PCI0PIN | 7 | Define Interrupt PCI0 on Pin D7
PCI0TRIGGER | 10 | Falling Edge, using internal Pull-up

Action which turns Relais ON at Pin D6 and is triggered by the remote control:
ACTION0.NODE | 1 | React to remote control with Nodeid 1
ACTION0.PORT | 6 | switch Pin D6
ACTION0.MASK | 2 | if bit (PCI0) is set, take action. | x | x | x | x | x | x | PCI0 | x
ACTION0.ONOFF | 1 | turn pin HIGH | x | x | x | x | x | x | 0 | 1

Action which turns Relais OFF at Pin D6 and is triggered by the remote control:
ACTION1.NODE | 1 | React to remote control with Nodeid 1
ACTION1.PORT | 6 | switch Pin D6
ACTION1.MASK | 4 | if bit (PCI1) is set, take action. | x | x | x | x | x | PCI 1 | x | x
ACTION1.ONOFF | 0 | turn pin LOW | x | x | x | x | x | x | 0 | 0

Action which toggles Relais on Pin 6, triggered by the tactile switch button on Pin 6 of the Smart-Socket:
ACTION2.NODE | 22 | React to an interrupt on my device
ACTION2.PORT | 6 | switch pin D6
ACTION2.MASK | 1 | PCI 0 triggerd by D7
ACTION2.ONOFF | 2 | toggle Pin | x | x | x | x | x | x | 1 | 0

Action which toggles the LED at Pin 8 of the Smart-Socket, triggered by the tactile switch button at the Smart-Socket:
ACTION3.NODE | 22 | React to an interrupt on my device
ACTION3.PORT | 8 | switch pin D8
ACTION3.MASK | 1 | PCI 0 triggerd by D7
ACTION3.ONOFF | 2 | toggle Pin | x | x | x | x | x | x | 1 | 0

alternatively, permanent illumination of the LED can be replaced by a short pulse:
ACTION3.ONOFF | 7 | Pulse with 1 second duration

Action which turns the LED at the Smart-Socket ON, triggered by the remote control
ACTION4.NODE | 1 | React to remote control with Nodeid 1
ACTION4.PORT | 8 | switch pin D8
ACTION4.MASK | 2 | if bit (PCI0) is set, take action. | x | x | x | x | x | x | PCI0 | x
ACTION4.ONOFF | 1 | turn pin HIGH | x | x | x | x | x | x | 0 | 1

alternatively, permanent illumination of the LED can be replaced by a short pulse:
ACTION4.ONOFF | 7 | Pulse with 1s duration (3 for a Pulse with 1/2 second)

Action which turns the LED at the Smart-Socket ON, triggered by the remote control
ACTION5.NODE | 1 | React to remote control with Nodeid 1
ACTION5.PORT | 8 | switch pin D8
ACTION5.MASK | 4 | if bit (PCI1) is set, take action. | x | x | x | x | x | PCI 1 | x | x
ACTION5.ONOFF | 0 | turn pin LOW | x | x | x | x | x | x | 0 | 0

alternatively, permanent illumination of the LED can be replaced by a short pulse:
ACTION5.ONOFF | 7 | Pulse with 1s duration (3 for a Pulse with 1/2 second)

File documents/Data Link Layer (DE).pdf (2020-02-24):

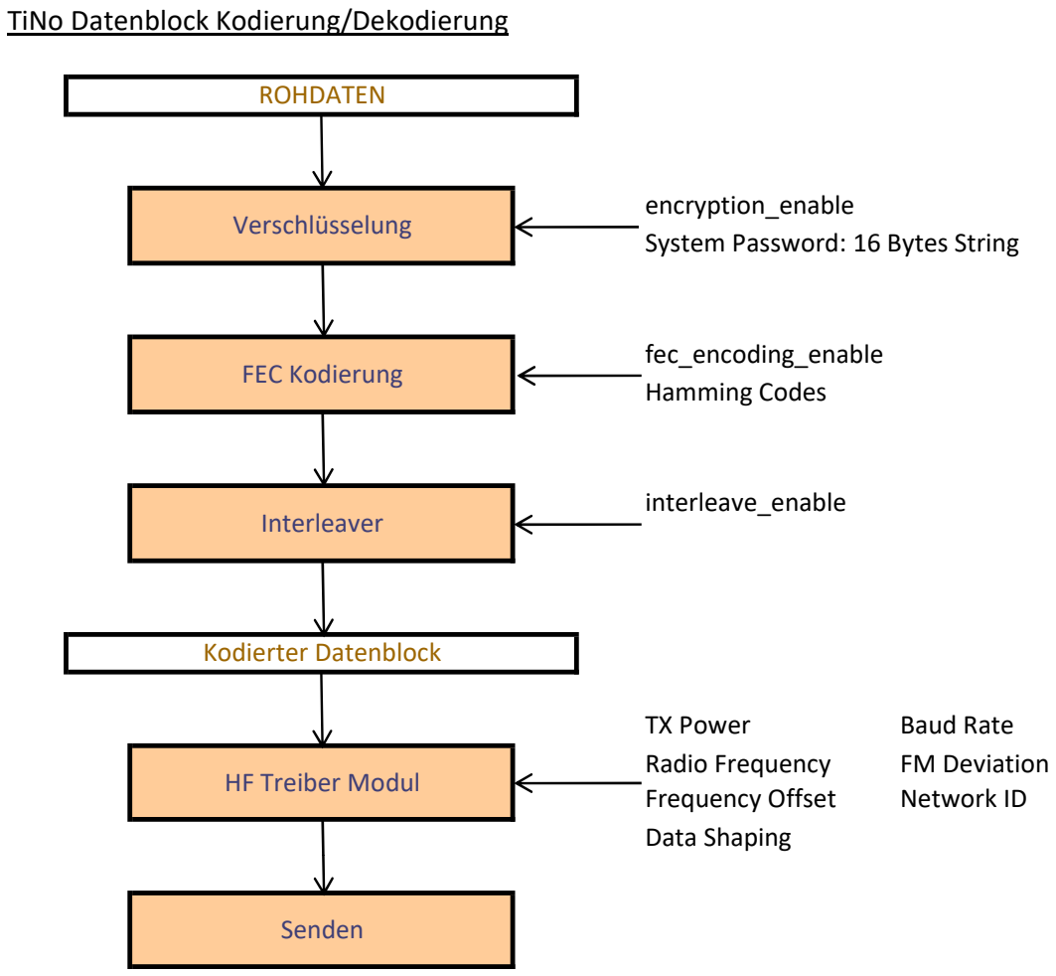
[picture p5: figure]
TiNo Datenblock Kodierung/Dekodierung; encryption_enable System Password: 16 Bytes String; fec_encoding_enable Hamming Codes; interleave_enable; TX Power; Baud Rate; Radio Frequency; FM Deviation; Frequency Offset; Network ID; Data Shaping; HF Treiber Modul; ROHDATEN; Verschlüsselung; FEC Kodierung; Interleaver; Kodierter Datenblock; Senden

Bemerkungen:
1. Kodierungsart wird im EEPROM konfiguriert. Die Konfiguration muss bei Sensor (Sender) und Gateway (Empfänger) identisch sein.

### 2. FEC Kodierung verdoppelt die Anzahl der Bytes im Datenblock LENenc = 2 * LENraw

3. Interleaver ist nur zusammen mit FEC sinnvoll.

### 4. FEC Kodierung mit 8/4 Hamming Codes (macht die Implementierung einfach)

5. Die Präambel, inklusive dem LEN byte ist NICHT kodiert.

TiNo Data Block Decoding

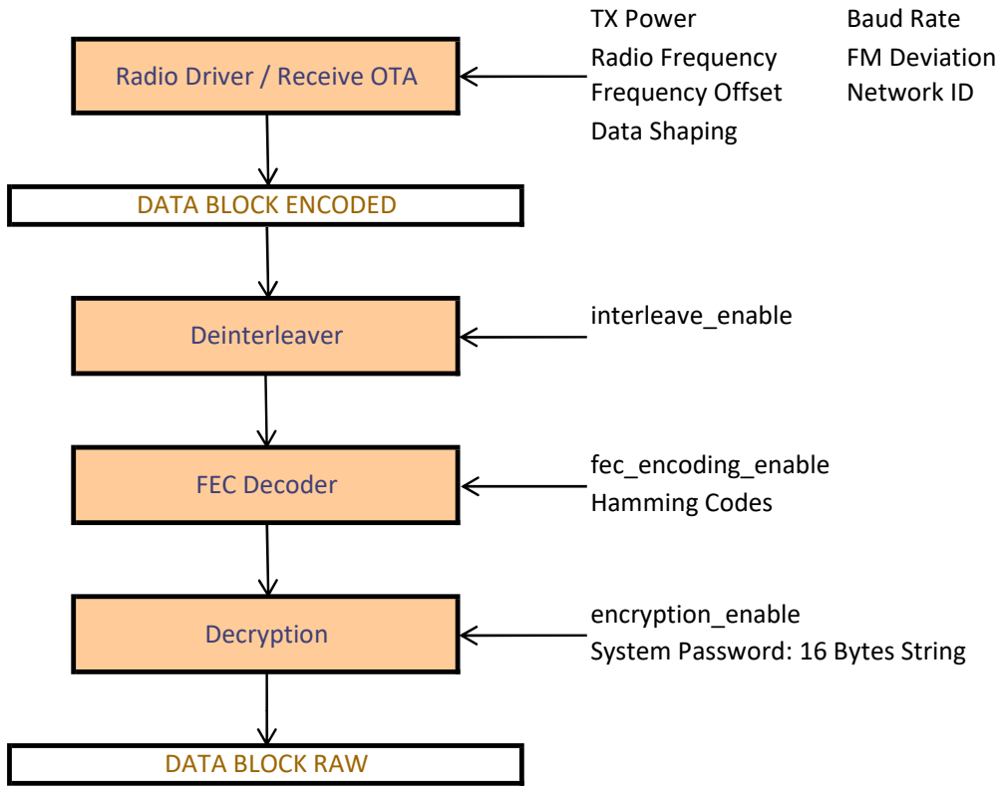
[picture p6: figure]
TX Power; Baud Rate; Radio Frequency; FM Deviation; Frequency Offset; Network ID; Data Shaping; interleave_enable; fec_encoding_enable Hamming Codes; encryption_enable System Password: 16 Bytes String; Radio Driver / Receive OTA; DATA BLOCK ENCODED; Deinterleaver; FEC Decoder; Decryption; DATA BLOCK RAW

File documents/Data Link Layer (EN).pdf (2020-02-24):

## TiNo Data Block Encoding/Decoding

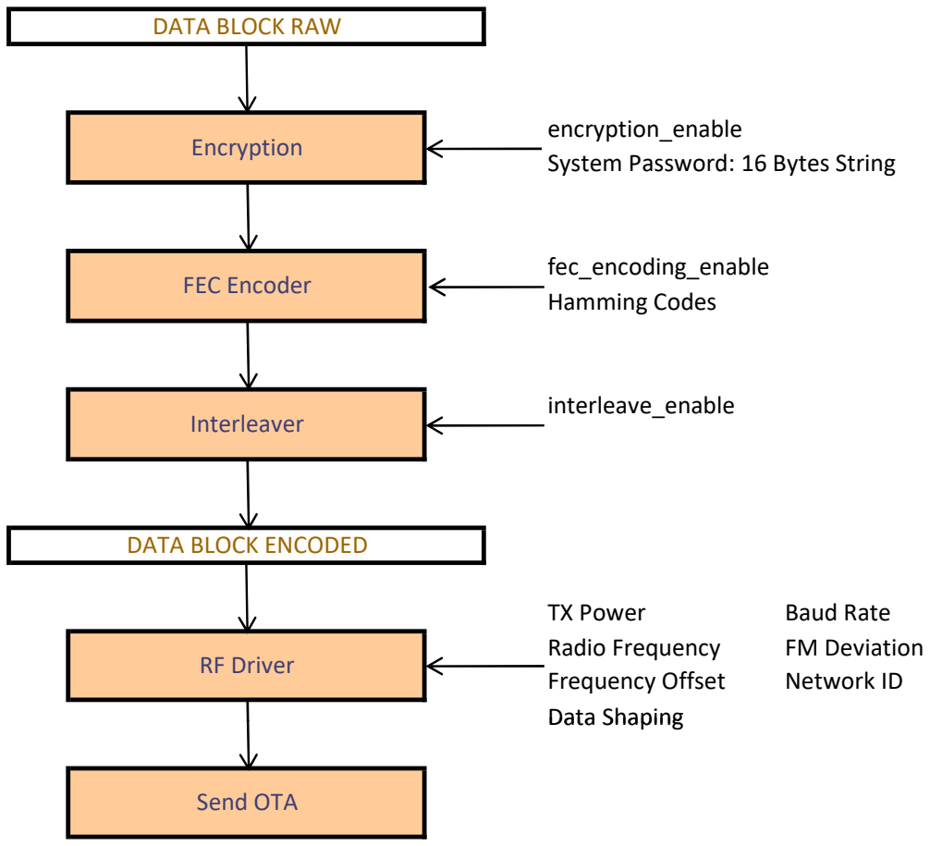
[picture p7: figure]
encryption_enable System Password: 16 Bytes String; fec_encoding_enable Hamming Codes; interleave_enable; TX Power; Baud Rate; Radio Frequency; FM Deviation; Frequency Offset; Network ID; Data Shaping; RF Driver; DATA BLOCK RAW; Encryption; FEC Encoder; Interleaver; DATA BLOCK ENCODED; Send OTA

Notes:
1. Coding is configured in EEPROM. Configuration must be same in Sensor (Sender) and gateway(receiver)

### 2. FEC Encoding doubles the number of Bytes in DATA BLOCK LENenc = 2 * LENraw

3. Interleaver is only useful together with FEC, otherwise its useless.

### 4. FEC Encoder is using 8/4 Hamming Codes (for simplicity of implementation) 5. Preamble, including LEN byte is NOT encoded

TiNo Data Block Decoding

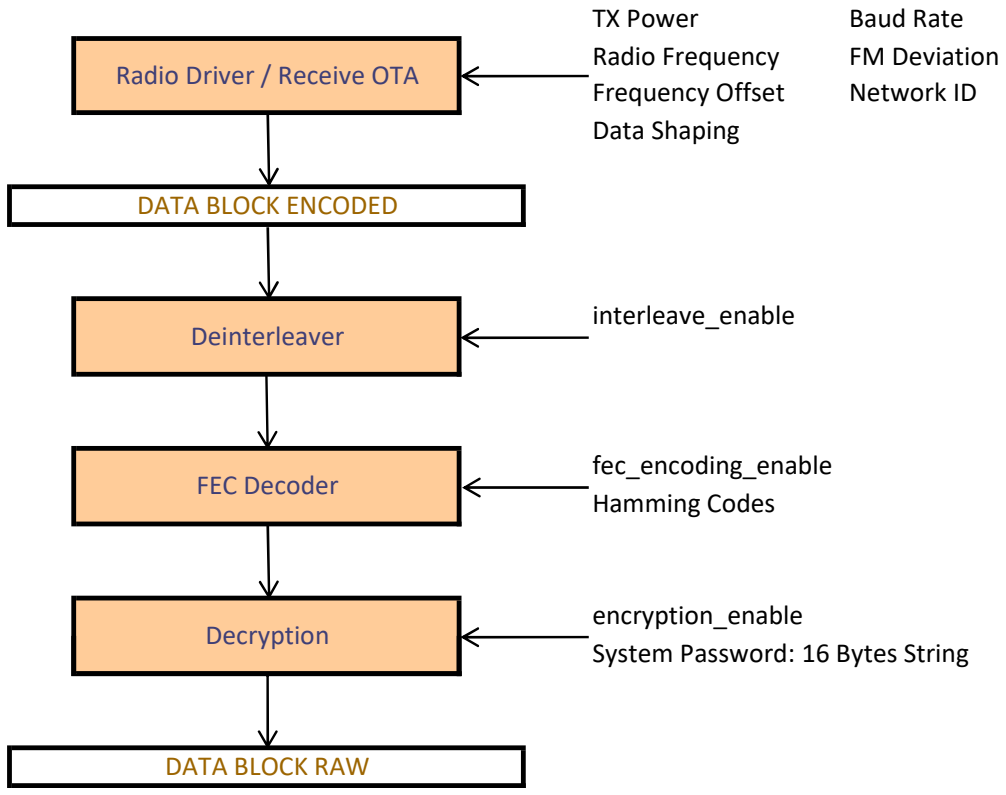
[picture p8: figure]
TX Power; Baud Rate; Radio Frequency; FM Deviation; Frequency Offset; Network ID; Data Shaping; interleave_enable; fec_encoding_enable Hamming Codes; encryption_enable System Password: 16 Bytes String; Deinterleaver; FEC Decoder; Decryption; DATA BLOCK ENCODED; Radio Driver / Receive OTA; DATA BLOCK RAW

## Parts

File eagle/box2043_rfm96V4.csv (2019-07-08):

Part | Value | Device | Package | Description | MF | MPN | OC_FARNELL | OC_NEWARK | PACKAGE | PROD_ID | SF_SKU | SPICEPREFIX | SUPPLIER
A0 |  | SMD2 | SMD1,27-2,54 | SMD PAD
A1 |  | SMD2 | SMD1,27-2,54 | SMD PAD
BAT |  | SN2032 | SN2032 | LI BATTERY
C1 | 100nF | C-EUC0603 | C0603 | CAPACITOR, European symbol |  |  |  |  |  |  |  | C
C2 | 100nF | C-EUC0603 | C0603 | CAPACITOR, European symbol |  |  |  |  |  |  |  | C
C3 | 0.1uF | CAP0603-CAP | 0603-CAP | Capacitor
C4 | 100nF | C-EUC0603 | C0603 | CAPACITOR, European symbol |  |  |  |  |  |  |  | C
C5 |  | C-EUC0402 | C0402 | CAPACITOR, European symbol |  |  |  |  |  |  |  | C
C6 |  | C-EUC0402 | C0402 | CAPACITOR, European symbol |  |  |  |  |  |  |  | C
C7 | 100nF | C-EUC0603 | C0603 | CAPACITOR, European symbol |  |  |  |  |  |  |  | C
C8 | 100nF | C-EUC0603 | C0603 | CAPACITOR, European symbol |  |  |  |  |  |  |  | C
D9 |  | SMD2 | SMD1,27-2,54 | SMD PAD
GND |  | SMD2 | SMD1,27-2,54 | SMD PAD
ISP1 |  | MA03-2 | MA03-2 | PIN HEADER |  |  | unknown | unknown
LED | DNP | LEDCHIPLED_0603 | CHIPLED_0603 | LED
LED1 | DNP | LED3MM | LED3MM | LED
LED2 |  | LEDCHIPLED_0603 | CHIPLED_0603 | LED
N1 |  | SMD2 | SMD1,27-2,54 | SMD PAD
Q1 |  | CRYSTALTC26V | TC26V | CRYSTAL |  |  | unknown | unknown
R1 | 1k | R-EU_R0603 | R0603 | RESISTOR, European symbol
R2 | 47k | R-EU_R0603 | R0603 | RESISTOR, European symbol
R3 | 1k0 | R-EU_R0603 | R0603 | RESISTOR, European symbol
R4 | 10k | R-EU_R0603 | R0603 | RESISTOR, European symbol
R5 | 10k | R-EU_R0603 | R0603 | RESISTOR, European symbol
R6 | 10k | R-EU_R0603 | R0603 | RESISTOR, European symbol
R7 | 1k0 | R-EU_R0603 | R0603 | RESISTOR, European symbol
S1 | MOMENTARY-SWITCH-SPST-PTH-RIGHT-ANGLE | MOMENTARY-SWITCH-SPST-PTH-RIGHT-ANGLE | TACTILE_SWITCH_PTH_RIGHT_ANGLE | Momentary Switch (Pushbutton) - SPST |  |  |  |  |  | CONN-10672 | COM-10791
SCL |  | SMD2 | SMD1,27-2,54 | SMD PAD
SDA |  | SMD2 | SMD1,27-2,54 | SMD PAD
SV1 |  | MA06-1 | MA06-1 | PIN HEADER |  |  | unknown | unknown
SV3 |  | MA06-1 | MA06-1 | PIN HEADER |  |  | unknown | unknown
U1 | ATMEGA328P-AU | ATMEGA328P-AU | QFP80P900X900X120-32N | 8-bit Microcontroller with In-System Programmable Flash |  | ATMEGA328P-AU | 1715486 | 14R4631 | TQFP-32 |  |  |  | Atmel
U2 | RFM95 | RFM95 | RFM95/96 | Low Power Long Range Transceiver Module. The RFM95/96/97/98(W) transceivers feature the LoRaTM long range modem that provides ultra-long range spread spectrum communication and high interference immunity whilst minimising current consumption.
U3 | HTU21D | HTU21D | DFN-6-3X3-HTU21D | Measurement Specialties HTU21D Relative Humidity Sensor w/ Temperature |  |  |  |  |  | IC-11793
X1 | BU-SMA-V | BU-SMA-V | BU-SMA-V | FEMALE SMA CONNECTOR |  |  | unknown | unknown

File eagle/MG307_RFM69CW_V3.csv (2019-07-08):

Part | Value | Device | Package | Description | MF | MPN | OC_FARNELL | OC_NEWARK | PACKAGE | PROD_ID | SPICEPREFIX | SUPPLIER | VALUE
ANT | WIREPAD1,6/0,9 | WIREPAD1,6/0,9 | 1,6/0,9 | Wire PAD connect wire on PCB
BAT1 |  | SN2032 | SN2032 | LI BATTERY
C1 | 100nF | C-EUC0603 | C0603 | CAPACITOR, European symbol |  |  |  |  |  |  | C
C2 | 100nF | C-EUC0603 | C0603 | CAPACITOR, European symbol |  |  |  |  |  |  | C
C3 | 0.1uF | CAP0603-CAP | 0603-CAP | Capacitor
C4 | 100nF | C-EUC0603 | C0603 | CAPACITOR, European symbol |  |  |  |  |  |  | C
C6 |  | C-EUC0402 | C0402 | CAPACITOR, European symbol |  |  |  |  |  |  | C
C7 |  | C-EUC0402 | C0402 | CAPACITOR, European symbol |  |  |  |  |  |  | C
ISP |  | PINHD-2X3 | 2X03 | PIN HEADER
J1 |  | CONN_06SILK_FEMALE_PTH | 1X06 | Multi connection point. Often used as Generic Header-pin footprint for 0.1 inch spaced/style header connections |  |  |  |  |  | CONN-08437
J2 | 455-1750-1-ND | CONN_03 | 1X03 | Multi connection point. Often used as Generic Header-pin footprint for 0.1 inch spaced/style header connections |  |  |  |  |  | XXX-00000 |  |  | 455-1750-1-ND
J3 |  | CONN_02 | 1X02 | Multi connection point. Often used as Generic Header-pin footprint for 0.1 inch spaced/style header connections
J6 |  | CONN_04 | 1X04 | Multi connection point. Often used as Generic Header-pin footprint for 0.1 inch spaced/style header connections |  |  |  |  |  | CONN-09696
LED |  | LEDCHIPLED_0603 | CHIPLED_0603 | LED
Q1 |  | CRYSTALTC26V | TC26V | CRYSTAL |  |  | unknown | unknown
R1 | 47k | R-EU_R0603 | R0603 | RESISTOR, European symbol
R2 | 1k | R-EU_R0603 | R0603 | RESISTOR, European symbol
R3 | 1k | R-EU_R0603 | R0603 | RESISTOR, European symbol
R4 | 1k | R-EU_R0603 | R0603 | RESISTOR, European symbol
R6 | 10k | R-EU_R0603 | R0603 | RESISTOR, European symbol
U1 | ATMEGA328P-AU | ATMEGA328P-AU | QFP80P900X900X120-32N | 8-bit Microcontroller with In-System Programmable Flash |  | ATMEGA328P-AU | 1715486 | 14R4631 | TQFP-32 |  |  | Atmel
U2 | HTU21D | HTU21D | DFN-6-3X3-HTU21D | Measurement Specialties HTU21D Relative Humidity Sensor w/ Temperature |  |  |  |  |  | IC-11793
U3 | RFM69CW | RFM69CW | RFM69CW | The RFM69CW is a low-power, low cost radiotransceiver that is capable of operating in the 434MHz and 900MHz open bands. It supports OOK, FSK and GFSK Modulation. It is pin compatible to the RFM12B

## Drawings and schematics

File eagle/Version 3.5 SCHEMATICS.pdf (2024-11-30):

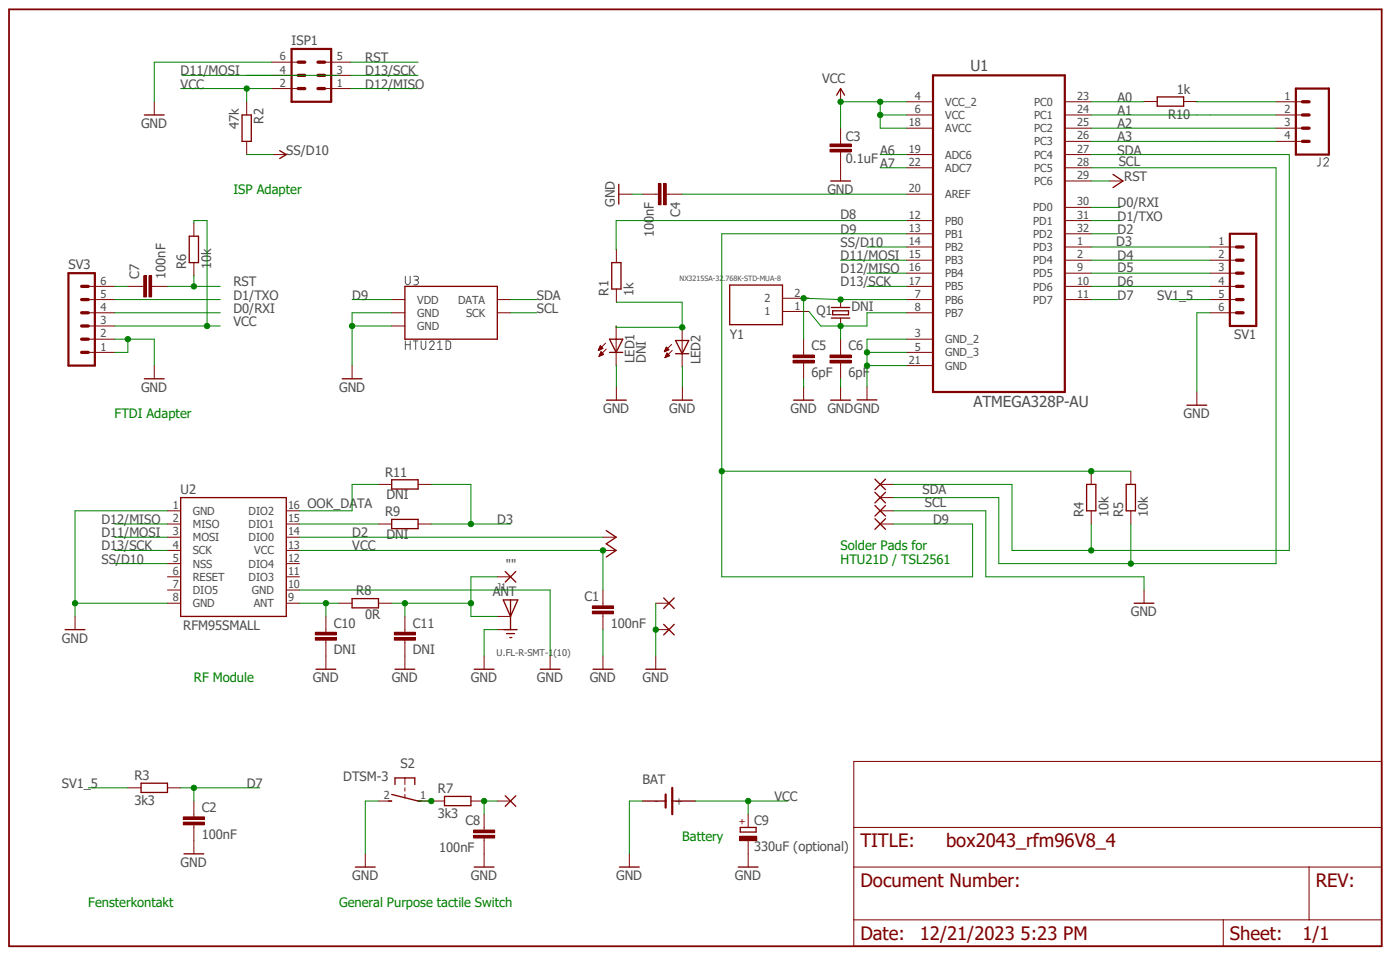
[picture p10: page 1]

General Purpose tactile Switch

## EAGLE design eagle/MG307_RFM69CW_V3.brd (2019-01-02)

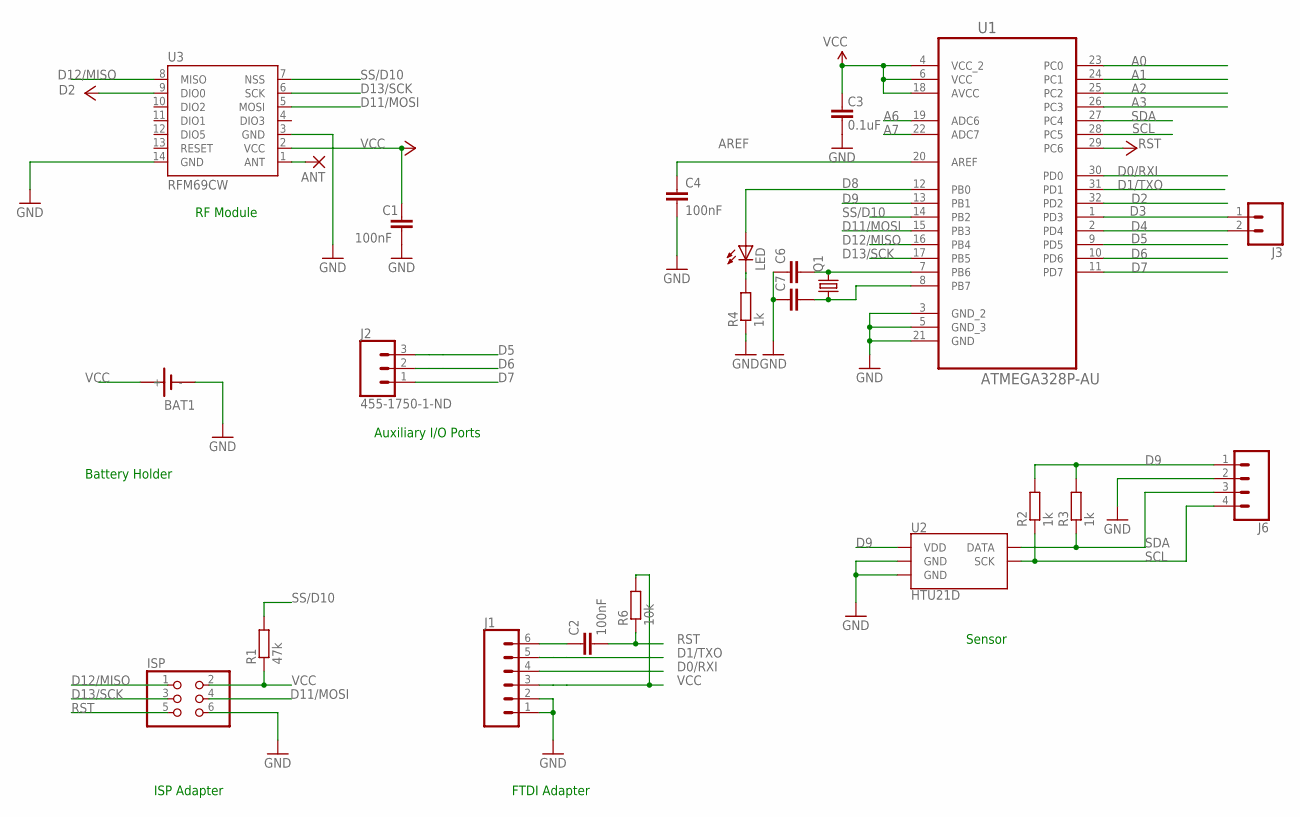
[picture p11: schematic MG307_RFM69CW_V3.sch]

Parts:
ANT: WIREPAD1,6/0,9; 1,6/0,9
BAT1: SN2032
C1, C2, C4: 100nF; C0603
C3: 0.1uF; 0603-CAP
C6, C7: C-EUC0402; C0402
ISP: PINHD-2X3; 2X03
J1: CONN_06SILK_FEMALE_PTH; 1X06
J2: 455-1750-1-ND; 1X03
J3: CONN_02; 1X02
J6: CONN_04; 1X04
LED: LEDCHIPLED_0603; CHIPLED_0603
Q1: CRYSTALTC26V; TC26V
R1: 47k; R0603
R2, R3, R4: 1k; R0603
R6: 10k; R0603
U1: ATMEGA328P-AU; QFP80P900X900X120-32N
U2: HTU21D; DFN-6-3X3-HTU21D
U3: RFM69CW

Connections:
A0: U1.23 (PC0)
A1: U1.24 (PC1)
A2: U1.25 (PC2)
A3: U1.26 (PC3)
A6: U1.19 (ADC6)
A7: U1.22 (ADC7)
ANT: ANT.1, U3.1 (ANT)
AREF: C4.1, U1.20 (AREF)
D0/RXI: J1.4, U1.30 (PD0)
D1/TXO: J1.5, U1.31 (PD1)
D2: U1.32 (PD2), U3.9 (DIO0)
D3: J3.1, U1.1 (PD3)
D4: J3.2, U1.2 (PD4)
D5: J2.3, U1.9 (PD5)
D6: J2.2, U1.10 (PD6)
D7: J2.1, U1.11 (PD7)
D8: LED.A, U1.12 (PB0)
D9: J6.1, R2.2, R3.2, U1.13 (PB1), U2.VDD
D11/MOSI: ISP.4, U1.15 (PB3), U3.5 (MOSI)
D12/MISO: ISP.1, U1.16 (PB4), U3.8 (MISO)
D13/SCK: ISP.3, U1.17 (PB5), U3.6 (SCK)
DTR: C2.1, J1.6
GND: BAT1.-, C1.2, C3.1, C4.2, C6.1, C7.1, ISP.6, J1.1, J1.2, J6.2, R4.1, U1.3 (GND_2), U1.5 (GND_3), U1.21 (GND), U2.7 (GND), U2.GND, U3.3 (GND), U3.14 (GND)
GND1: LED.C, R4.2
unnamed: C6.2, Q1.2, U1.7 (PB6)
unnamed: C7.2, Q1.1, U1.8 (PB7)
RESET: U3.13 (RESET)
RST: C2.2, ISP.5, R6.1, U1.29 (PC6)
SCL: J6.4, R2.1, U1.28 (PC5), U2.SCK
SDA: J6.3, R3.1, U1.27 (PC4), U2.DATA
SS/D10: R1.2, U1.14 (PB2), U3.7 (NSS)
VCC: BAT1.+, C1.1, C3.2, ISP.2, J1.3, R1.1, R6.2, U1.4 (VCC_2), U1.6 (VCC), U1.18 (AVCC), U3.2 (VCC)

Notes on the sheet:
RF Module
FTDI Adapter
ISP Adapter
Battery Holder
Auxiliary I/O Ports
Sensor

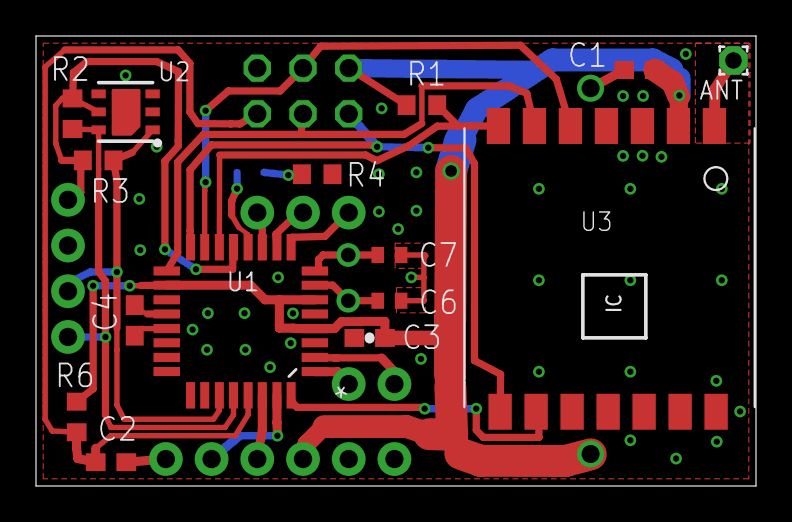
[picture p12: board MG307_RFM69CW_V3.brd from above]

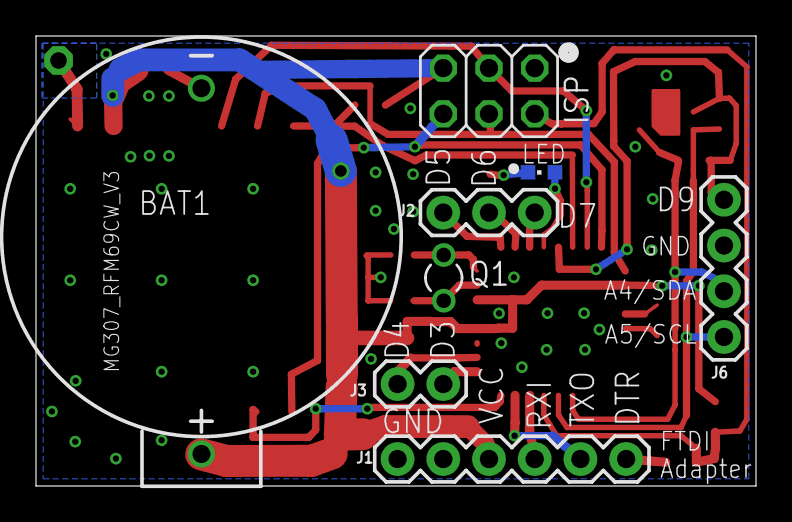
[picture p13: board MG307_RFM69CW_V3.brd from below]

Board: 2 copper layers, 40.0 x 25.0 mm, 23 parts (8 on the bottom side), 25 nets.

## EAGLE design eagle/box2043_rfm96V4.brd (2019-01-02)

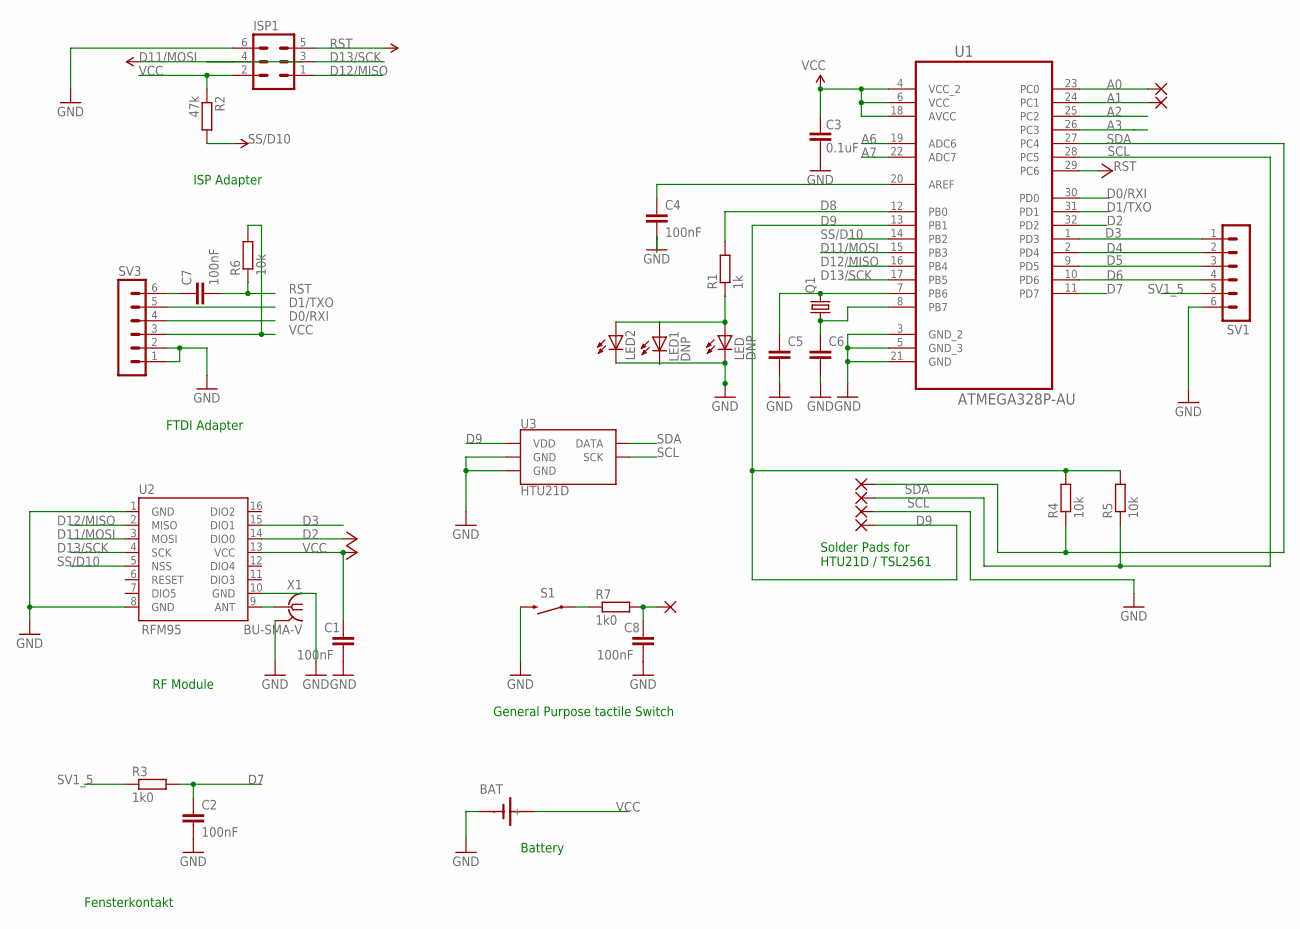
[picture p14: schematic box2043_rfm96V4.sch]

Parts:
A0, A1: SMD2; SMD1,27-2,54
BAT: SN2032
C1, C2, C4, C7, C8: 100nF; C0603
C3: 0.1uF; 0603-CAP
C5, C6: C-EUC0402; C0402
D9: SMD2; SMD1,27-2,54
GND: SMD2; SMD1,27-2,54
ISP1: MA03-2
LED: DNP; CHIPLED_0603
LED1: DNP; LED3MM
LED2: LEDCHIPLED_0603; CHIPLED_0603
N1: SMD2; SMD1,27-2,54
Q1: CRYSTALTC26V; TC26V
R1: 1k; R0603
R2: 47k; R0603
R3, R7: 1k0; R0603
R4, R5, R6: 10k; R0603
S1: MOMENTARY-SWITCH-SPST-PTH-RIGHT-ANGLE; TACTILE_SWITCH_PTH_RIGHT_ANGLE
SCL: SMD2; SMD1,27-2,54
SDA: SMD2; SMD1,27-2,54
SV1, SV3: MA06-1
U1: ATMEGA328P-AU; QFP80P900X900X120-32N
U2: RFM95; RFM95/96
U3: HTU21D; DFN-6-3X3-HTU21D
X1: BU-SMA-V

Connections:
A0: A0.1, U1.23 (PC0)
A1: A1.1, U1.24 (PC1)
A2: U1.25 (PC2)
A3: U1.26 (PC3)
A6: U1.19 (ADC6)
A7: U1.22 (ADC7)
D0/RXI: SV3.4, U1.30 (PD0)
D1/TXO: SV3.5, U1.31 (PD1)
D2: U1.32 (PD2), U2.14 (DIO0)
D3: SV1.1, U1.1 (PD3), U2.15 (DIO1)
D4: SV1.2, U1.2 (PD4)
D5: SV1.3, U1.9 (PD5)
D6: SV1.4, U1.10 (PD6)
D7: C2.1, R3.2, U1.11 (PD7)
D8: R1.2, U1.12 (PB0)
D9: D9.1, R4.2, R5.2, U1.13 (PB1), U3.VDD
D11/MOSI: ISP1.4, U1.15 (PB3), U2.3 (MOSI)
D12/MISO: ISP1.1, U1.16 (PB4), U2.2 (MISO)
D13/SCK: ISP1.3, U1.17 (PB5), U2.4 (SCK)
DTR: C7.1, SV3.6
GND: BAT.-, C1.2, C2.2, C3.1, C4.2, C5.2, C6.2, C8.2, GND.1, ISP1.6, LED.C, LED1.K (C), LED2.C, S1.2, SV1.6, SV3.1, SV3.2, U1.3 (GND_2), U1.5 (GND_3), U1.21 (GND), U2.1 (GND), U2.8 (GND), U2.10 (GND), U3.7 (GND), U3.GND, X1.2, X1.3 (2), X1.4 (2), X1.5 (2)
unnamed: U2.9 (ANT), X1.1
unnamed: C5.1, Q1.2, U1.7 (PB6)
unnamed: C4.1, U1.20 (AREF)
unnamed: R7.1, S1.1
unnamed: LED.A, LED1.A, LED2.A, R1.1
unnamed: C6.1, Q1.1, U1.8 (PB7)
unnamed: C8.1, N1.1, R7.2
RESET: U2.6 (RESET)
RST: C7.2, ISP1.5, R6.1, U1.29 (PC6)
SCL: R5.1, SCL.1, U1.28 (PC5), U3.SCK
SDA: R4.1, SDA.1, U1.27 (PC4), U3.DATA
SS/D10: R2.2, U1.14 (PB2), U2.5 (NSS)
SV1_5: R3.1, SV1.5
VCC: BAT.+, C1.1, C3.2, ISP1.2, R2.1, R6.2, SV3.3, U1.4 (VCC_2), U1.6 (VCC), U1.18 (AVCC), U2.13 (VCC)

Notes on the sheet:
ISP Adapter
Solder Pads for HTU21D / TSL2561
Fensterkontakt
Battery
RF Module
FTDI Adapter
General Purpose tactile Switch

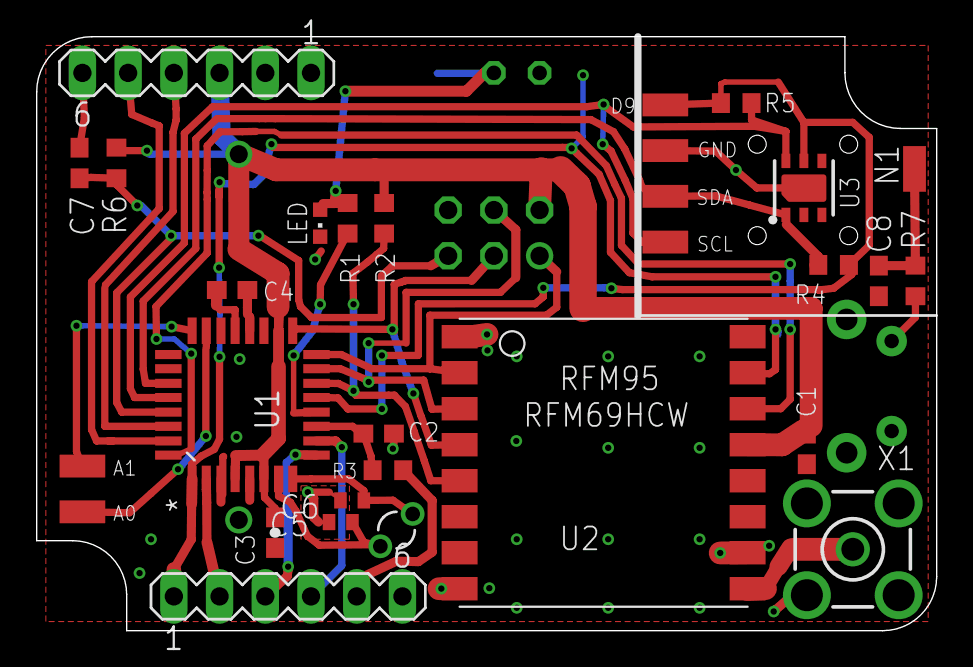
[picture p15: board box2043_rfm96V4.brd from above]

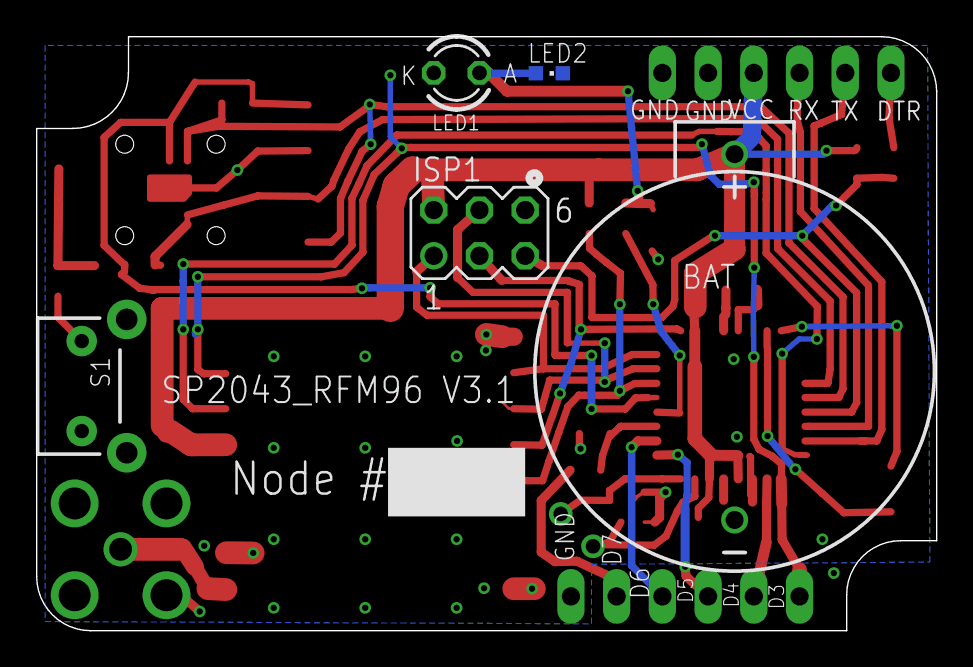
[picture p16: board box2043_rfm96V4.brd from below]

Board: 2 copper layers, 50.0 x 33.0 mm, 35 parts (5 on the bottom side), 30 nets.

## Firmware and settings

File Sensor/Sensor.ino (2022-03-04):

// RFM69CW Sender for temperature / humidity Sensors with Watchdog.
// Supports Sensors with HTU21D, SHT20, SHT21, SHT25, SHT30, SHT31, SHT35, BME280, DS18B20
// built for AVR ATMEGA328P
// optional possibility to use  a 32.768 crystal to reduce sleep current to ~1.5 µA

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
// Licence can be viewed at
// http://www.fsf.org/licenses/gpl.txt

// Please maintain this license information along with authorship
// and copyright notices in any redistribution of this code
// *********************************************************************************

/*****************************************************************************/
/***  Third Party libraries used in this project                           ***/
/*****************************************************************************/
// Uses LowPower from  https://github.com/rocketscream/Low-Power under creative commons attribution-sharealike 3.0 unported license. see https://creativecommons.org/licenses/by-sa/3.0/
// Uses HTU21D_SoftI2C modified from https://github.com/enjoyneering/HTU21D under BSD licence, rewritten by nurazur for use of SoftwareWire
// Uses SoftwareWire Version 1.4.1. from https://github.com/Testato/SoftwareWire under GNU General Public License v3.0
// Uses a RFM69 Driver originally from LowPowerlab.com However this driver has been changed so much so that it is barely recognizable.
// Uses PinChangeInterrupt from https://github.com/NicoHood/PinChangeInterrupt under open source license, exact type is not specified but looks like GNU
// uses a modified BME280 Driver from https://github.com/finitespace/BME280 under GNU General Public License version 3 or later
// Uses OneWire             // license terms not clearly defined.
// Uses DallasTemperature under GNU LGPL version 2.1 or any later version.
// Uses SHT3x_sww.h - license: "Created by Risele for everyone's use (profit and non-profit)."
// Uses MAX31865 from Ole Wolf <wolf@blazingangles.com> at https://github.com/olewolf/arduino-max31865.git under GNU General Public License version 3 or later
//
/* Revision history:
    Build 3:
        Support for EEPROM selected MAC functions (Encryption, FEC, Interleaving)
        Support for external Crystal, compiler option (because of interfering ISR's)
        RFM69CW TX Gauss shaping adjustable
    Build 4:
        Support for RFM69HCW, P1 Mode, P1+2 Mode, Pa Boost mode.
    Build 5:
        Add Serial port enable in Config settings
    Build 6:
        Implement MAC Class
        cleanup code, remove obsolete defines and comments. Support ACK's
    Build 7:
        FEI alignment in calibration
        EEPROM encrypted
    Build 9: various improvements. VCC is now tested during TX Burst. Support DS18B20 Temperature Sensor, SHT30x, BME280

    Build 10:
        one firmware for all sensors
        support for LDR (brightness reading), requires a analog pin (A0 or A1)
        choice of sleep mode can be set in configuration - WDT vs crystal timer
        possible External Heartbeat using TPL5110
        for each PCINT a individual Gateway ID (multi-channel remote control)
        calibration mode: 't' sends a dummy packet
        calibration mode: 'to' starts den OOK Modus (send a CW signal)
        calibration mode: 'tt' retrieves the Tepmerature reading from the RFM69 chip
        calibration mode: Offset for RFM69 temperature in configuration
        Receiver can output locally measured sensor data (HTU21D only in this release)
*/
#include "pins_arduino.h"
#include "HardwareSerial.h"

#define USE_RADIO

#define FILENAME "TiNo 3.0.1 Sender.ino 03/03/2022"
#define BUILD 10

/*****************************************************************************/
/***   MAC                                                                 ***/
/*****************************************************************************/
#include <datalinklayer.h>



/*****    which Sensor  do you want to use? select 1 sensor only (2 sensors at your own risk)     *****/
#define USE_HTU21D
//#define USE_BME280
#define USE_DS18B20
#define USE_SHT3X
#define USE_MAX31865


typedef struct
{
    byte HTU21D:1;
    byte DS18B20:1;
    byte BME280:1;
    byte SHT3X:1;
    byte MAX31865:1;
    byte BRIGHTNESS:1;
    byte Reserved:2;

} UseBits;


class sensors
{
    public:
        UseBits use;


        sensors (UseBits sensor_cfg)
        {
            this->use = sensor_cfg;
            PacketLen =  0;
            this->calc_packettype();
            this->count(0);
            this->temp1(0);
            this->temp2(0);
        }

        int8_t calc_packettype(void)
        {
            // prefer SHT3x over HTU21D in case both are present.
            // currently there is no Packet type for 2 humidity sensors.
            if (use.HTU21D && use.SHT3X)
            {
                use.HTU21D=0;
            }

            // no packet type available for 2 humidity sensors. BME280 preferred.
            if (use.BME280 && (use.HTU21D || use.SHT3X))
            {
                PacketType = 0;
                use.HTU21D =0;
                use.SHT3X =0; // don't use the humidity sensors in this case!
            }

            this->is_temperature_sensor = use.HTU21D || use.BME280 || use.DS18B20 || use.SHT3X || use.MAX31865;
            this->is_humidity_sensor = use.HTU21D || use.BME280 || use.SHT3X;


            // no explicit temperature sensor on board, i.e for Interrupts only like a remote control
            if (!is_temperature_sensor)
            {
                PacketType = 0;
            }
            else if (use.HTU21D || use.SHT3X)
            {
                if (use.DS18B20 || use.MAX31865)
                {
                    PacketType = 5;  // 1 additional external Temp sensor
                }
                else
                {
                    // default
                    PacketType = 0;
                }
            }

            // air pressure
            else if (use.BME280)
            {
                PacketType = 0;
            }

            // Temperature sensors only: up to 3
            else if (use.DS18B20 || use.MAX31865)
            {
                if (!is_humidity_sensor)
                {
                    PacketType = 4;
                }
            }
            else
                PacketType =-1;

            switch (PacketType)
            {
                case 0:
                    pData = (uint8_t*) &t0;
                    if (!use.BME280  && !use.BRIGHTNESS){
                        PacketLen = 8;
                    }
                    else{
                        PacketLen = sizeof(Payload);
                    }
                    break;
                case 4:
                    pData  = (uint8_t*) &t4;
                    PacketLen = sizeof(PacketType4);
                    t4.packet_type=4;
                    use.BRIGHTNESS=0; // brightness not possible with packet type 4
                    break;
                case 5:
                    pData= (uint8_t*) &t5;
                    t5.packet_type=5;
                    PacketLen = sizeof(PacketType5);
                    break;
                default:
                    break;
            }

            return PacketType;
        }

        void humidity(uint8_t h)
        {
            switch(this->PacketType)
            {
                case 0:
                    t0.humidity = h;
                    break;
                case 5:
                    t5.humidity = h;
                    break;
                default:
                    break;
            }
        }

        void pressure(uint32_t p)
        {
            if (this->PacketType == 0)
            {
                t0.pressure = p;
            }
        }

        void targetid(uint8_t t) {pData[0] = t;}
        void nodeid  (uint8_t n) {pData[1] = n;}
        void flags   (uint8_t f)
        {
            pData[2] = f;
            if (this->PacketType !=0)
                pData[2] |= 0x20;
        }

        uint8_t flags(void)
        {
            return pData[2];
        }

        void count(uint8_t c)
        {
            switch(this->PacketType)
            {
                case 0:
                    t0.count = c;
                    break;
                case 4:
                case 5:
                    pData[3] = c;
                    break;
                default:
                    break;
            }
        }

        void increment_count(void)
        {
            switch(this->PacketType)
            {
                case 0:
                    t0.count++;
                    break;
                case 4:
                    t4.count++;
                    if (t4.count == 0) t4.count_msb++;
                    break;
                case 5:
                    t5.count++;
                    break;
                default:
                    break;
            }
        }

        void supplyV(uint16_t v)
        {
            switch(this->PacketType)
            {
                case 0:
                    t0.supplyV = v;
                    break;
                case 4:
                    t4.supplyV = v;
                    break;
                case 5:
                    t5.supplyV = v;
                    break;
                default:
                    break;
            }
        }

        void temp(uint16_t t)
        {
            switch(this->PacketType)
            {
                case 0:
                    t0.temp = t;
                    break;
                case 4:
                    t4.temp = t;
                    break;
                case 5:
                    t5.temp = t;
                    break;
                default:
                    break;
            }
        }

        void temp1(uint16_t t)
        {
            switch(this->PacketType)
            {
                case 4:
                    t4.temp1 = t;
                    break;
                case 5:
                    t5.temp1 = t;
                    break;
                default:
                    break;
            }
        }

        void temp2(uint16_t t)
        {
            if (this->PacketType == 4)
            {
                t4.temp2 = t;
            }
        }

        void brightness(uint16_t b)
        {
            switch(this->PacketType)
            {
                case 0:
                    t0.brightness = b;
                    break;
                case 5:
                    t5.brightness = b;
                    break;
                default:
                    break;
            }
        }

        int8_t PacketType;
        uint8_t PacketLen;
        uint8_t is_temperature_sensor;
        uint8_t is_humidity_sensor;

        union
        {
            Payload t0;
            PacketType4 t4;
            PacketType5 t5;
        };

        uint8_t *pData;
};


sensors *Sensor=NULL;




/*****************************************************************************/
/***   Radio Driver Instance                                               ***/
/*****************************************************************************/
#include <RFM69.h>  // select this radio driver for RFM69HCW and RFM69CW Modules from HopeRF
//#include <CC1101.h>  // select this driver for CC1101 Modules
RADIO radio;

/*****************************************************************************/
/***  EEPROM Access  and device calibration                                ***/
/*****************************************************************************/
#include "configuration.h"
#include "calibrate.h"

/*****************************************************************************/
/***                            Encryption                                 ***/
/*****************************************************************************/
//encryption is OPTIONAL by compilation switch
//to enable encryption you will need to:
// - provide a 16-byte encryption KEY (same on all nodes that talk encrypted)
// - set the varable ENCRYPTION_ENABLE to 1 in the EEPROM, at runtime in Cfg.EncryptionEnable

#define KEY     "TheQuickBrownFox"

/*****************************************************************************/
/***                            Serial Port                                ***/
/*****************************************************************************/
// SoftwareSerial is NOT by default compatible with PinchangeInterrupt!
// only Hardwareserial is supported. Baud rate must be 4800 because Avr runs on 1MHz only and RC-oscillator clock
#define SERIAL_BAUD     4800
HardwareSerial *mySerial = &Serial;




/*****************************************************************************/
/***                   Device specific Configuration                       ***/
/*****************************************************************************/
Configuration Config;


/*****************************************************************************/
/***                   Data Link Controller                                ***/
/*****************************************************************************/
myMAC Mac(radio, Config, (uint8_t*) KEY);


/*****************************************************************************/
/***                   Calibration Module                                  ***/
/*****************************************************************************/
Calibration CalMode(Config, mySerial, &Mac, BUILD, (uint8_t*) KEY);



/*****************************************************************************/
/*** Sleep mode choice ***/
/*****************************************************************************/
uint16_t watchdog_counter;
bool watchdog_expired = false;
#include "LowPower.h"

ISR(TIMER2_COMPA_vect)
{
}
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
void loop()
{
    static bool timer2_setup_done = false;

    // go to sleep. When waking up, restart from here.
    if (Config.Senddelay != 0)
    {
        if (Config.UseCrystalRtc)
        {
            LowPower.powerSave(SLEEP_FOREVER, ADC_OFF, BOD_OFF, TIMER2_ON); // wake up on timer2 counter overflow
        }
        else // use WDT
        {
            LowPower.powerDown(SLEEP_8S, ADC_OFF, BOD_OFF);
        }
    }
    else // Senddelay is 0, external timer or no timer (like in a remote control)
    {
        if (Config.UseCrystalRtc)
        {
            timer2_setup_done = true;
        }
        TCCR2B &= 0xF8; // timer 2 off, CS0=0, CS1=0, CS2=0
        LowPower.powerDown(SLEEP_FOREVER, ADC_OFF, BOD_OFF);
    }


    if (!event_triggered)
    {
        watchdog_counter++;
    }


    // activate PIR after it has triggered some time ago (the dead time)
    if (Config.PirPowerPin >=0)
    {
        pir_dead_time_expired = (watchdog_counter >= Config.PirDeadTime) && pir_is_off; // if true, turn on VCC of PIR and wait 2.5s
        if (pir_dead_time_expired)
        {
            pir_is_off = false;
            digitalWrite(Config.PirPowerPin, HIGH);
            pir_dead_time_expired = false;
            if (Config.SerialEnable) { Serial.println("PIR active."); Serial.flush(); }

            // when PIR ist switched ON, event triggers and we need to wait for 2.5s because data pin goes high for 2.5s
            LowPower.powerDown(SLEEP_500MS , ADC_OFF, BOD_OFF);
            LowPower.powerDown(SLEEP_2S, ADC_OFF, BOD_OFF);

            event_triggered &= 0xFD; //1111 1101 clear bit 1, this is PCI1 from PIR Sensor
        }
    }

    watchdog_expired = ((watchdog_counter >= Config.Senddelay) && (Config.Senddelay != 0)); // when Senddelay equals 0, sleeep forever and wake up only for events.
    if (watchdog_expired || event_triggered)
    {
        uint8_t Flags = 0;
        float temperature=0;
        uint16_t humidity =0;

        if (!Config.UseCrystalRtc)
        {
            enableADC(true); // power up/enable the ADC
        }

        if (watchdog_expired)
        {
            // reset the watchdog counter
            watchdog_counter = 0;

            // there is a strange behaviour of the Atmega328, we need to redo the timer 2 setup once.
            if (Config.UseCrystalRtc && !timer2_setup_done)
            {
                timer2_setup_done =true;
                setup_timer2(); // this restarts the timer
            }

            // set the heartbeat flag when the watchdog counter is expired
            Flags |= 0x01;
        }

        Sensor->targetid(Config.Gatewayid);

        if(event_triggered)
        {
            Flags |= (event_triggered << 1);
            //um Fernbedienungen mit mehreren Kanaelen herzustellen, muss der Node
            //Pakete an verschiedene Nodeid's schicken koennen.
            switch (event_triggered)
            {
                case 0x01:
                    Sensor->targetid(Config.PCI0Gatewayid);
                    break;
                case 0x02:
                    Sensor->targetid(Config.PCI1Gatewayid);
                    break;
                case 0x04:
                    Sensor->targetid(Config.PCI2Gatewayid);
                    break;
                case 0x08:
                    Sensor->targetid(Config.PCI3Gatewayid);
                    break;
                default:
                    break;
            }
        }
        Sensor->flags(Flags);

        // PIR Sensor triggered: turn off Sensor for PIR_DEAD_TIME seconds
        if (Config.PirPowerPin >=0)
        {
            if (event_triggered & 0x2)//PCI1
            {
                pir_is_off = true;
                digitalWrite(Config.PirPowerPin, LOW);
                watchdog_counter =0;
                if (Config.SerialEnable)
                {
                    Serial.println("PIR triggered."); Serial.flush();
                }
                blink(Config.LedPin, 3);
            }
        }

        long Vcal_x_ADCcal = (long)Config.AdcCalValue * Config.VccAtCalmV;
        #ifdef USE_RADIO
            Sensor->supplyV( Vcal_x_ADCcal / radio.vcc_dac );  // the VCC measured during last TX Burst.
        #else
            Sensor->supplyV( Vcal_x_ADCcal / readVcc() );
        #endif

        Sensor->increment_count();

        if(Sensor->use.HTU21D)
        {
            Measure_HTU21D(temperature, humidity, Config);
        }

        if (Sensor->use.SHT3X)
            Measure_SHT3x(temperature, humidity);

        if(Sensor->use.BME280)
        {
            uint32_t p=0;
            Measure_BME280(temperature, humidity, p, Config.I2CPowerPin);
            Sensor->pressure(p);
        }

        if (Sensor->use.DS18B20)
        {
            switch (Sensor->PacketType)
            {
                case 5:
                    {
                        float t;
                        Measure_DS18B20(&t);
                        Sensor->temp1(encode_temp(t));
                    }
                    break;
                case 4:
                    {
                        uint16_t t1,t2;
                        Measure_DS18B20(&temperature, &t1, &t2);
                        Sensor->temp1(t1);
                        Sensor->temp2(t2);
                    }
                    break;
                default:
                    break;
            }
        }


        if (Sensor->use.MAX31865) // PT100 is not by default available in classic TiNo with Atmega328P
        {
            #if defined USE_MAX31865 || defined __AVR_ATmega644P__ || defined (__AVR_ATmega1284P__)
            float t=0;
            uint8_t status = Measure_MAX31865(&t);
            Sensor->temp1(encode_temp(t));
            if(Config.SerialEnable)
            {
                mySerial->print("RTD status: ");
                mySerial->println(status);
            }
            #endif
        }

        if(Sensor->use.BRIGHTNESS && Config.LdrPin >= 0)
        {
            uint16_t brightness = brightness_with_LDR(Config.LdrPin);
            Sensor->brightness( brightness );
            mySerial->print("LDR: ");
            mySerial->println( brightness );
        }

        if (!Sensor->is_temperature_sensor)
        {
            mySerial->println("no temp sensor");
            #ifdef USE_RADIO
                temperature = radio.readTemperature(0) + Config.radio_temp_offset/10.0;
            #else
                temperature = 12.34;
            #endif
            if (Config.Senddelay != 0) delay(65); // add delay to allow wdtimer to increase in case its erroneous
        }

        Sensor->temp( encode_temp(temperature) );
        Sensor->humidity(humidity);

        if (Config.SerialEnable)
        {
            if (Sensor->is_humidity_sensor)
            {
                mySerial->print(humidity/2.0);
                mySerial->print(" %RH\t");
            }

            mySerial->print(temperature, 2); mySerial->println("º");
        }


        bool ackreceived = false;
        #ifdef USE_RADIO
        temperature<0?  temperature-=0.5 : temperature+=0.5;

        if(Config.UseRadioFrequencyCompensation)
        {
            ackreceived = Mac.radio_send(Sensor->pData, Sensor->PacketLen, Config.RequestAck, int(temperature));
        }
        else
        {
            ackreceived = Mac.radio_send(Sensor->pData, Sensor->PacketLen, Config.RequestAck);
        }

        if (Config.RequestAck && Config.SerialEnable)
            (ackreceived) ? mySerial->println("Ack received.") : mySerial->println(" No Ack received.");
        #endif

        //#ifndef USE_CRYSTAL
        if (!Config.UseCrystalRtc)
            enableADC(false); // power down/disable the ADC
        //#endif

        event_triggered = 0;


        if (ackreceived)
        {
            activityLed (1, 100);
        }

        if (Config.LedPin && Config.LedCount >0)
        {

            if (Config.LedCount != 0xff) Config.LedCount--;
            blink(Config.LedPin, 2); // blink LED
        }
        if (Config.SerialEnable) mySerial->flush();
    }
}

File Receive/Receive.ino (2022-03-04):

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
// Licence can be viewed at
// http://www.fsf.org/licenses/gpl.txt

// Please maintain this license information along with authorship
// and copyright notices in any redistribution of this code
// *********************************************************************************



// Gateway for the TiNo Wireless Sensor System
//
// Based originally on work from Nathan Chantrell
// modified by meigrafd @2013 - for UART on RaspberryPI
// extended by nurazur nurazur@gmail.com 2014 - 2019
// the RF protocol is completely binary, see https://github.com/nurazur/tino


#define SKETCHNAME "TiNo 3.0.1 receive.ino Ver 03/03/2022"
#define BUILD 10


#include <avr/sleep.h>
#include <HardwareSerial.h>
#define SERIAL_BAUD 38400
#ifdef SOFTSERIAL
    #define RX_PIN 0
    #define TX_PIN 1
    #include <SoftwareSerial.h>
    SoftwareSerial swserial(RX_PIN, TX_PIN);
    SoftwareSerial *mySerial = &swserial;
#else
    HardwareSerial *mySerial = &Serial;
#endif


#include "configuration.h"
#include <datalinklayer.h>

/* For TiNo-HP, TiNo-LC, TiNo-SW1, TiNo-SW  the RFM69 library is included */
//#include <RFM69.h>
#include <RFM69.h>
/* For TiNo-HPCC the CC1101 library is included. comment out the RFM69 library and uncomment the below line. */
//#include <CC1101.h>

#include <EEPROM.h>
#include "calibrate.h"

#define KEY  "TheQuickBrownFox"

/*****************************************************************************/
/***                            I2C Driver                                 ***/
/*****************************************************************************/
// SHT21/HTU21D connects through SoftwareWire, so that SCL and SDA can be any pin
// Add pullup resistors between SDA/VCC and SCL/VCC if not yet provided on Module board
#include "SoftwareWire.h"
SoftwareWire *i2c = NULL;

// if I2C bus has no pullups externally, you can use internal Pullups instead.
// Internal pullup resistors are ~30kOHm. Since we are clocking slowly,
// it works. However, they need to be disabled in sleep mode, because SoftwareWire
// keeps them enabled even if i2c is ended with end()
#define USE_I2C_PULLUPS  true // use this for HTU21D in case no Pullups are mounted.
//#define USE_I2C_PULLUPS false // use this in case external Pullups are used.


/*****************************************************************************/
/***                       HTU21D                                          ***/
/*****************************************************************************/

#define USE_HTU21D

#ifdef USE_HTU21D
#include "HTU21D_SoftwareWire.h"
HTU21D_SoftI2C *myHTU21D =NULL;
#endif


/*****************************************************************************/
/***                       Actions                                         ***/
/*****************************************************************************/
typedef struct {
  uint8_t node;      // the node to trigger
  uint8_t port;      // the port to trigger
  uint8_t mask;      // to which bit of the flag byte it is mapped
  uint8_t onoff;    // type of action:  OFF (00) ON(01) TOGGLE (10) PULSE (11); Pulse length = 2^B, where B = bits [23456], B= (action[i] >>2) &0xf, C = default on power up, C = bit[7] 1= on, 0 = off
} action;

#define ADR_NUM_ACTIONS sizeof(Configuration)+272u
#define ADR_ACTIONS   ADR_NUM_ACTIONS + 1
#define MAX_NUM_ACTIONS 40

action *actions;
uint8_t num_actions;
/*
if action.node is equal to this node, then the flag word in the telegram is evaluated.
4 flags can be set (bits 1 to bit 4 in the flag byte). Each flag is mapped to a port using the mask byte.
the port is defined in the port[i] array (up to 4 different ports for the four flags)
Actions are: ON, OFF, TOGGLE Port, PULSE with length 2^B * 0.5 seconds.

Example: Node 15,  Port 7 shall turn on on flag 02, port 7 shall turn off on flag 04. Port 8 shall be toggled on flag 0x08, Port 5 shall be pulsed for 2 seconds on flag 0x10

node = 15;
port = 7;
mask = 0x02;
onoff = 0x1;

node = 15;
port = 7;
mask = 0x04;
onoff = 0x0;

node = 15;
port = 8;
mask = 0x08;
onoff = 0x10;

node = 15;
port = 5;
mask = 0x10;
onoff = 0x3 | (0x02 << 2); // B=2, 2^B = 4 * 0.5s = 2s
*/

unsigned char pulse_port=0;  // the port for which a pulse is defined and active.
unsigned int pulse_duration=0; // counter
void setup_watchdog(int timerPrescaler);

void doaction (uint8_t nodeid, uint8_t flags, action actions[], uint8_t num_actions)
{
    for (uint8_t i=0; i< num_actions; i++)
    {
        if(actions[i].node == nodeid) // nodeid matches the actions's nodeId
        {
            if (actions[i].mask & flags ) // the action's trigger bit is set
            {
                uint8_t act = actions[i].onoff &0x3; // Action mode
                switch (act)
                {
                    case 0:     // OFF
                        digitalWrite(actions[i].port, 0);
                        break;
                    case 1:     // ON
                        digitalWrite(actions[i].port, 1);
                        break;
                    case 2:     // Toggle
                        digitalWrite(actions[i].port, !digitalRead(actions[i].port));
                        break;
                    case 3:     //Pulse
                        digitalWrite(actions[i].port, 1);
                        pulse_port = actions[i].port;

                        uint8_t exp = (actions[i].onoff>>2) &0x7F;

                        if (exp <= 4) // less than or equal 8 seconds
                        {
                            pulse_duration  =1;
                            setup_watchdog(5+exp);
                        }
                        else // more than  8s
                        {
                            pulse_duration = pow(2,exp-4);
                            setup_watchdog(9); //8s
                        }
                        break;
                }
            }
        }
    }
}


static void Start_HTU21D(Configuration &Config)
{

    #ifdef USE_HTU21D
    i2c->beginTransmission (HTDU21D_ADDRESS);
    if (i2c->endTransmission() == 0)
    {
        if (Config.SerialEnable) mySerial->println ("Found HTU21D");
        myHTU21D = new HTU21D_SoftI2C(i2c);
        delay(100);
        myHTU21D->begin();
        myHTU21D->setResolution(HTU21D_RES_RH10_TEMP13);
    }
    else
    {
        //blink(Config.LedPin, 3);
        if (Config.SerialEnable) mySerial->println ("Could not find a HTU21D");
    }
    #endif
}
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

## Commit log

2018-11-26 initial commit - added project files
    [receive_eeprom.cfg, send_eeprom.cfg]
2018-11-26 added libraries Mac, calibration, configuration, RFM69
2018-11-29 add JSON file for Arduino IDE
2019-01-02 add eagle PCB designs
    [MG307_RFM69CW_V3.brd, MG307_RFM69CW_V3.sch, box2043_rfm96V4.brd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]
2019-01-05 Link to PCB design directory added
2019-07-08 Add BOM for PVB's
    [MG307_RFM69CW_V3.csv, box2043_rfm96V4.csv]
2019-09-04 RF drivers have now a generic abstract base class. This allows in future to add new hardware easily, independent from higher software levels. "mac" is renamed to "data link layer" whis is better unde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
2019-09-04 new calibration tools for version 2.0, ready for python 3
    [tino_HP_eeprom.cfg, tino_LC_eeprom.cfg]
2019-09-04 example sketches for sensor and gateway, version 2.0
2019-09-04 add library for BME280 with SoftwareWire I2C bus driver support
2019-09-05 Test Arduino IDE for version 2.0.0
2019-09-05 Test Arduino IDE with version 2.0.1 (published)
2019-09-06 provide correct configuaration tool for Raspberry Pi
    [tinocal_v009.py]
2020-02-24 update: BME280 Sensor is supported
2020-02-27 update Arduino IDE .json file for version 2.1.0
2020-04-24 HTU21D Sensor for HomeMatic
2021-05-29 new sensors: MAX31865 and AM312
2021-05-31 correct typo (wrong braces)
    [Sensor.ino]
2021-07-03 Bug fix: correct serial outputs.
    [Receive.ino, Sensor.ino]
2021-08-26 Correction of version and date in welcome string
    [Receive.ino, Sensor.ino]
2022-03-04 initial release 3.0.1
    [receive_eeprom.cfg, tino_HP_eeprom.cfg, tino_LC_eeprom.cfg]
2022-03-04 update package index for arduino IDE
2022-03-04 update receive.ino (bug fix)
    [Receive.ino]
2022-09-02 configuration tool: some minor bug fixes some minor improvements add possibility to define a bit in bitfields in configuration files. example: sensorconfig.brightness=1
    [tinocal_v010.py]
2024-11-30 add PCB Version 3.5 Gerber and schematics

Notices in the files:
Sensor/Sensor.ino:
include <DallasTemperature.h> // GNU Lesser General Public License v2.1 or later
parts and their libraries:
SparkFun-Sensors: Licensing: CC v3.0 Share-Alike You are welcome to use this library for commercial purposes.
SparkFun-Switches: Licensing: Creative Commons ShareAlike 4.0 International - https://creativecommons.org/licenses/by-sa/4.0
